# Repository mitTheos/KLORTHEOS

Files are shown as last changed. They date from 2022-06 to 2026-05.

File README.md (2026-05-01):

# Welcome to my take on the great KLOR Split Keyboard Project

My addition to the project includes the addition of a 5 way switch to the thumb cluster for the LP KS55 version with the revision 1.5.

I got inspiration for the usage of a 5way switch from [the Fulcrum project](https://github.com/dschil138/Fulcrum) and found the there described uses for it intriguing. The project however went into a different flavor of split kb then what I was looking for. The KLOR on the other hand matching that very well. My keyboard of choice before the KLOR was a Sofle. Which I was very happy with but still left somethign to be desired. Ultimately I wanted a keyboard that was:
- wireless
- had stronger row stagger than the Sofle
- had 5way switches
- had rotary encoders
- low profile
- used less keys than the Sofle

I think with my modification of the KLOR I should be able to check all of these boxes.

*To note: for the addition of the 5 way switch I removed the switch 22 (obviously) but also the audio buzzer and the trackball modules to make more space. I have no intention of using either one and the additional space that came with removing them made the routing a tad easier which was welcome as this was my first take on PCB modification.*

# Lefuneste's notes
Here you'll find an up do date version of KLOR PCB and firmware files for Rev 1.4 for full height Cherry switches and a Rev 1.4 LP KS33 version for low profile KS33 Gateron switches.

If you intend to build a KLOR keyboard from this repo please take the time to read the different sections below.

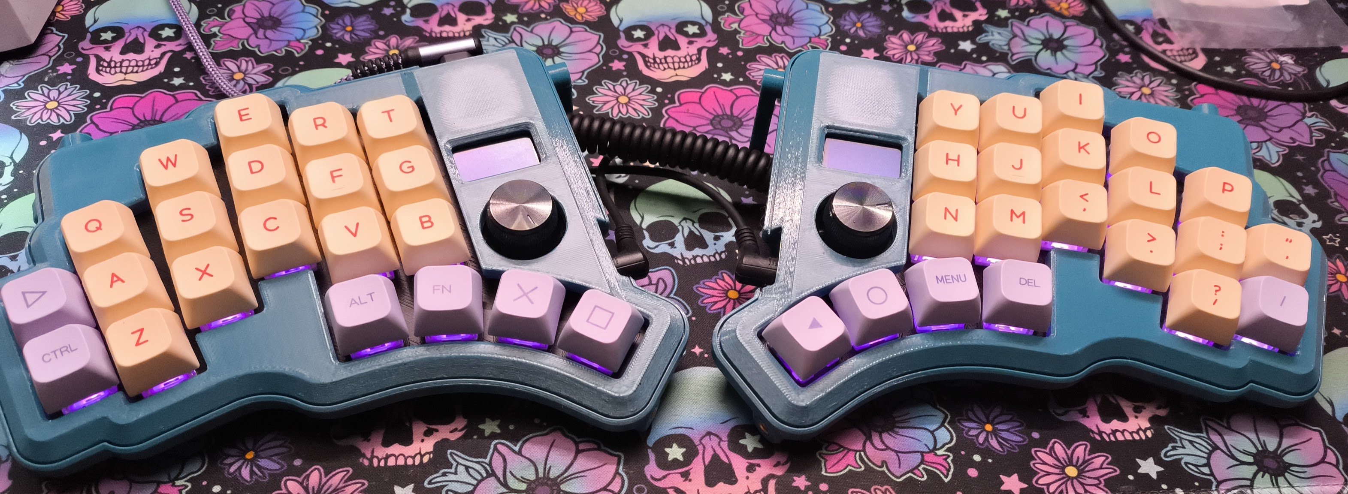
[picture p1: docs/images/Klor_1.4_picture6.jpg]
KLOR

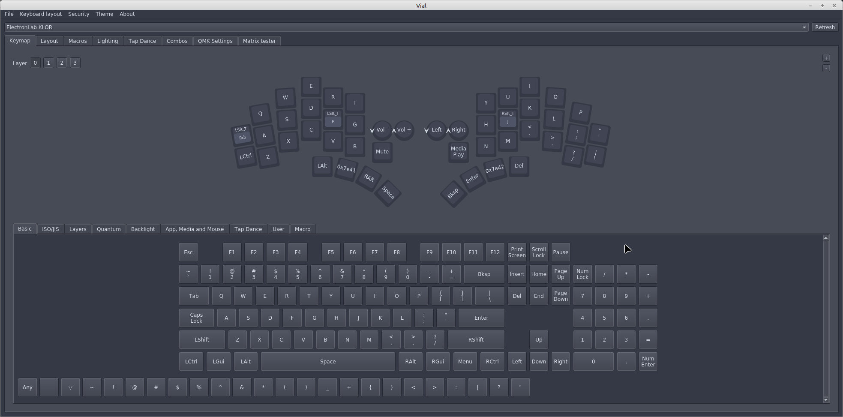
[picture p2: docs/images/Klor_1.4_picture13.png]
KLOR


### [CHANGELOG](https://github.com/Lefuneste83/KLOR/blob/main/CHANGELOG.md)

### [PCB FOR FULL HEIGHT SWITCHES (REV 1.4)](https://github.com/Lefuneste83/KLOR/tree/main/PCB/klor1_4)
-  This is my original initial design, derived from the 1.3 with lots of upgrades. I have built it and it works great. The south facing LED and the better suited LED packages make this the best choice for a first KLOR build. It keeps the overall design of the original in terms of PCB size and modularity. It is designed for MX style full height hotswap sockets. Gateron or Kailh sockets work great and probably other brands as well. This is not compatible with low profile sockets!

### [FABRICATION NOTES (FOR REV 1.4)](https://github.com/Lefuneste83/KLOR/blob/main/FABNOTES.md)
- These are my recommendations for first time builders of the KLOR keyboard. I suggest to have a read as they explain most tricky points that I have encountered while building mine.

### [PCB FOR LOW PROFILE GATERON KS33 SWITCHES (BETA VERSION REV 1.4 LP KS33)](https://github.com/Lefuneste83/KLOR/tree/main/PCB/klor1_4_LP_KS33)
-  This is a beta version derived from the 1.4 using low profile Gateron hotswap sockets for KS33 switches. It is a beta version so it will see lots of updates in the coming days. Don't rush to have it made except if you want to test it. In particular the haptic module will most likely interfere with the sockets and will require some filing of the haptic PCB. So it is not perfect yet.

### [PCB FOR ALTERNATIVE HAPTIC MODULE](https://github.com/Lefuneste83/KLOR/tree/main/PCB/Alternate%20DIY%20Haptic%20Module)
-  This is an alternative version of the haptic module for those who don't want to spend a fortune on the original one or can't source it. It is for advanced users as you will need some experience in SMD soldering and a hot air or hot plate to solder the linear actuator, and some form of magnification for the driver chip. It works great and is a bit shorter for easier integration. It mounts perfectly on all PCB versions except most likely on the low profile PCB because of the interference with the hotswap socket.

### [PCB FOR FULL HEIGHT SWITCHES CORRECTED STOCK VERSION (REV 1.3)](https://github.com/Lefuneste83/KLOR/tree/main/PCB/klor1_3)
-  This is as close as it gets to the original design but with some rerouting to allow to pass JLCPCB preproduction validation process. It uses the older style of LED (WS2812 3535) which are very tricky to solder properly, as they are not intended to be mounted this way. I strongly suggest moving to the 1.4 version for a much better build experience and a much more reliable build.

### [FIRMWARE](https://github.com/Lefuneste83/KLOR/blob/main/FIRMWARE.md)
-  VIAL support is now working on RP2040 with VIAL-QMK
-  These are updated QMK and ZMK config files and compiled images. They should have most devices enabled by default and should compile on latest toolchains of ZMK and QMK. A [Github Actions repositiry for ZMK](https://github.com/Lefuneste83/zmk-config-klor) is also available in my other repositories. Keep in mind that I only use ZMK on NRF52840 and QMK on RP2040. I would advise you to do the same as Atmega chips will not support all functionalities of the KLOR keyboard. As a reminder ZMK on NRF52840 will not support audio or haptic yet, but will support OLED to a certain degree and wireless communications with BLE protocol. QMK on RP2040 will support everything except wireless communications.

# CONTEXT
I have just completed my build of the 1.3 and found it a bit frustrating to assemble, despite my 13 year experience with this kind of project. Don't get me wrong the KLOR project is absolutely marvelous, but the PCB design starts to show its age IMHO, in the details of the layout in particular. Technology wise it is one, if not the best project out there hands down.

So here you will find a completely refactored PCB design of the KLOR project for 2024 including :

- Much better suited and easier to solder ARGB modules. I have used SK6812 Mini-E (aka 6028 size LED) version as it is the typical choice for this kind of keyboard application. I have thus kept the original paradigm of through hole design, with a symetrical front/back layout, but while using a LED module which is designed for this application, contrary to the original model WS2812 3535 which required a direct "hanged" soldering, with very likely damages to the plastic package as well as missalignment issues, as this part is designed for direct surface mount. I personnaly think that it would be even better to use the new WS2812 2020 package which is very neat, but as this is a strictly SMD part, there is no need for discrete cutouts anymore, so the design would look a bit different. Also you need to master SMD soldering. Let me know if you are interested in this type of LED package, I could make a forked design without too much fuss.

- As Hipyo Tech can confirm, we are in 2024 so no North facing LED are allowed anymore. I have moved to South facing LED.

- I have tried to keep the overall design paradigm so all the good stuff is still there!!

- I have very extensively refactored the PCB layout (3 days of intense work) to clean up the various little issues that were sprinkled around the original design including :

  Rerouting of 90% of the PCB. Healthier and more rational overall routing, at least that's my belief...
  
  Change to the footprint of the solder jumpers to triangular shapes much easier to bridge
  
  Correction of missing ground connections on the various switches bodies
  
  Dual ground planes thorough validation (this was painful)
  
  Very slight changes to the board cutout on the right side, to deal with reversed switch placement. Also very slight reduction of the cutout under the top of the MCU to catter some track celearance that would pop up in DRC. This should have no impact as this cutout serves no real purpose as far as I know. Cases and switchboards should mount the same, except for the ones using the puck cutout (see below).
  
  Very slight movement of the puck mounting holes downward (98.57 mm instead of 96.4 mm) by a couple milimeters to catter for reversed switches pad postions. I could not do otherwise without revisiting the switch layouts. I could not solve this by rotating the 3 mounting holes without interfering with other nets. It should not affect the mounting ability of the puck itself, but it WILL interfere with existing back cases using the puck cutout. So we will need specific cutouts for the case. As I don't have access to the original step model the best option would be to use some alternate case design provided with source files in order to lower the cutout by the same amount (2.17 mm).
  
  I managed a 0 error JLCPCB DRC, with only very few voluntary exceptions (down from 1000+). It took me several hours to clean up the various little issues that were sprinkled all around the orignial design. And I can confirm that Kicad on Linux is not a pleasure to use...
  
  Change of Logo with mine !

  This repo will be updated as I have new ideas for integrations of various tech or correction for errors.

  I have also included files for a working 1.3 design which passes the JLCPCB fabrication and is working as a real world product (REV 1.3)
  
***

<picture>
  <source media="(prefers-color-scheme: dark)" srcset="/docs/images/klor-font-logo-dark.svg">
  <source media="(prefers-color-scheme: light)" srcset="/docs/images/klor-font-logo-bright.svg">
  KLOR logo font
</picture>

# KLOR SPLIT KEYBOARD

KLOR is a 36-42 key column-staggered split keyboard. It supports a per-key RGB matrix, encoders, OLED displays, haptic feedback, speakers, a Pixart Paw3204 trackball, the [SplitKB tenting puck](https://splitkb.com/products/tenting-puck), and four different layouts, through break-off parts.

***

## RENDERING OF THIS FORK (Rev 1.4)

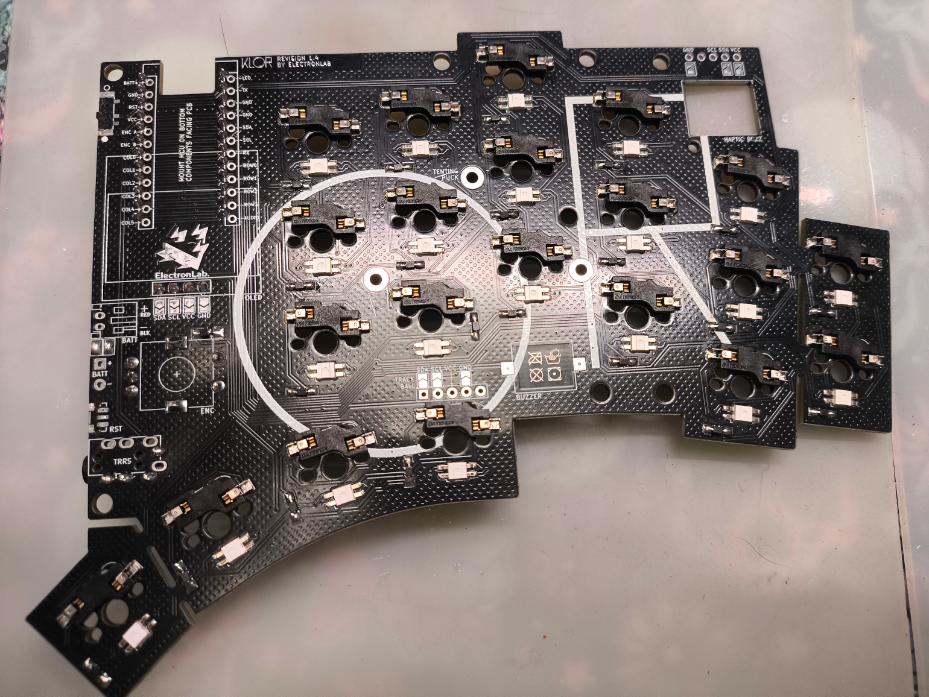
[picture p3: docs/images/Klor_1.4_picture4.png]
KLOR layouts

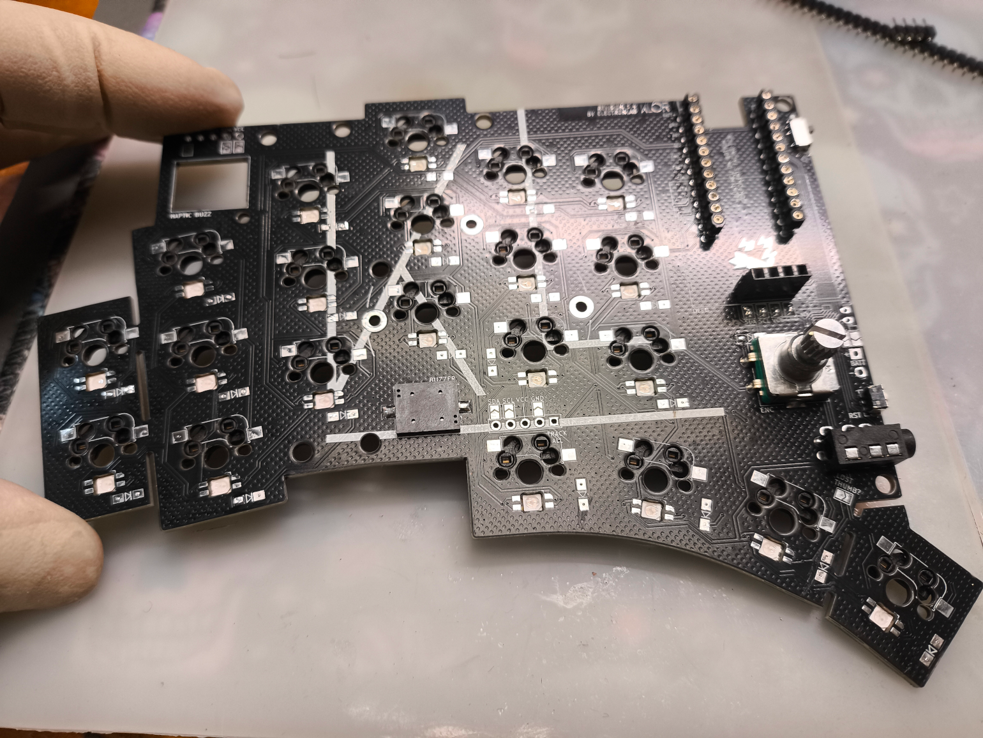
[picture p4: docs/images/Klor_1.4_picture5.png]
KLOR layouts

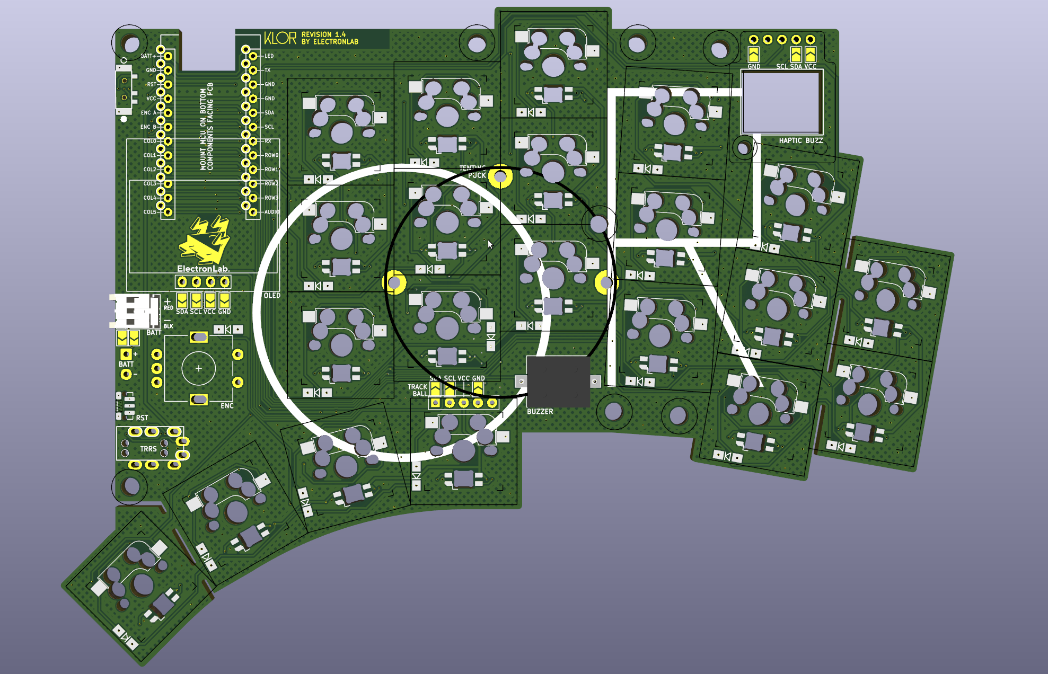
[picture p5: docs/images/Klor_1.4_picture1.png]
KLOR layouts

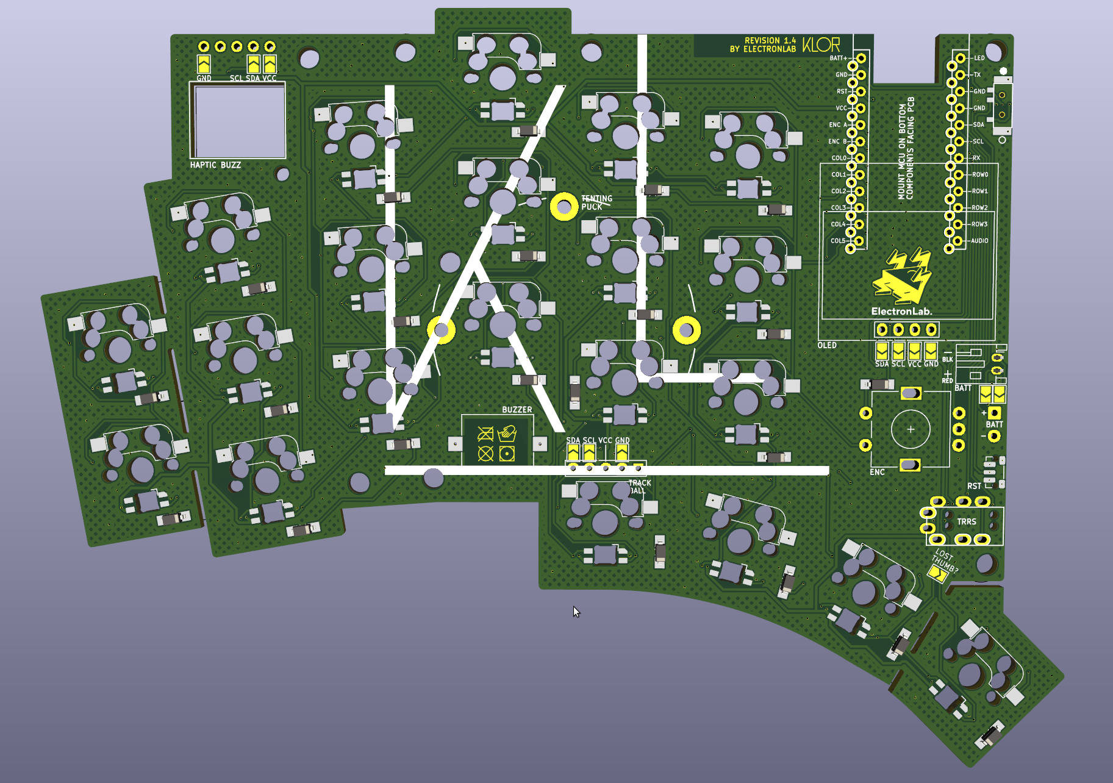
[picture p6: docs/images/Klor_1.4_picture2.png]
KLOR layouts

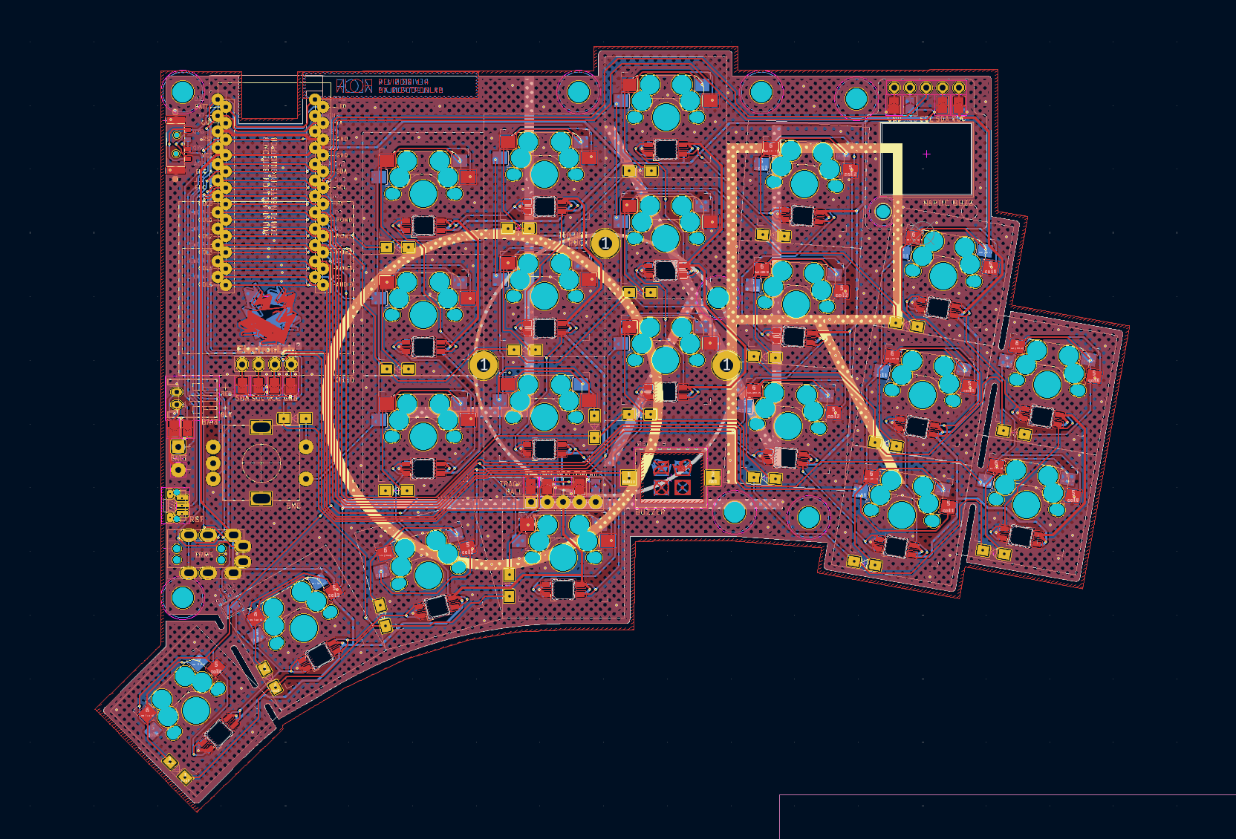
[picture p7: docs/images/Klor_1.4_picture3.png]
KLOR layouts


***

## LAYOUTS

KLOR layouts

***

## PCB 

[Here](/PCB/) you can find the KiCad files and Gerbers for the KLOR 1.3 (tested working with JLCPCB) and 1.4 (this version). 

***

## CASE

[Here](/case/) are the case files for the KLOR. There is an acrylic case and a 3D printed case (which uses acrylic too) for every layout.

***

## SWITCHPLATE

In every case directory you'll find the matching switchplates as **.dxf**, **.svg**, **.stl**, and a **.zip**-file, containing gerber files for a FR4 plate.

***

## KNOB

You can use pretty much any knob, which works with the EC11 encoder, but [here](/knob/) you can find one, I designed for the KLOR.

***

## BUILD GUIDE

Here you can find the build guides for the KLOR.\
[KLOR build guide 3DP case](/docs/buildguide_3DP.md) (QMK)\
[KLOR build guide stacked acrylic case](/docs/buildguide_acrylic.md) (QMK)\
[KLOR BLE build guide 3DP case](/docs/buildguide_3DP_ble.md) (ZMK)\
[KLOR BLE build guide stacked acrylic case](/docs/buildguide_acrylic_ble.md) (ZMK)

***

## CHOC/KS27 VERSION

[Sadek Baroudi](https://github.com/sadekbaroudi) did an amazing job in creating a version of the KLOR which supports KS-27 and Choc V1 switches. Including a special case for it.\
[KLOR Sadek KS-27 and Choc V1 mod](https://github.com/sadekbaroudi/KLOR)

***

## CREDITS

The KLORs hardware is based on the [Sofle](https://github.com/josefadamcik/SofleKeyboard) by [Josef Adamcik](https://github.com/josefadamcik).\
Other inspirations are 
- [Kyria](https://splitkb.com/products/kyria-pcb-kit) by [Thomas Baart](https://github.com/splitkb)
- [Yacc46](https://github.com/1m38/keyboards/tree/main/yacc46) by [1m38](https://github.com/1m38)
- [Elephant42](https://github.com/illness072/elephant42) by [illness072](https://github.com/illness072)
- [Torn](https://github.com/rtitmuss/torn) by [Richard Titmuss](https://github.com/rtitmuss)
- [Claw44](https://github.com/yfuku/claw44) by [yfuku](https://github.com/yfuku)

I used the Pimoroni Haptic Buzz Footprint from the [Buzzard](https://github.com/crehmann/Buzzard) by [Christoph Rehmann](https://github.com/crehmann).

***

People who helped me create this board and fix stuff
- [KarlK90](https://github.com/KarlK90)
- [MangoIV](https://github.com/MangoIV)
- [OxCB](https://github.com/0xCB-dev)
- [MicroFortnight](https://github.com/microfortnight)
- [dreipunkteinsvier](https://github.com/dreipunkteinsvier)

If you build a KLOR I would be pretty happy to see some pictures. And if you want to leave me a tip you can do this [here](https://ko-fi.com/geigeigeist) (but please don't feel pressured)

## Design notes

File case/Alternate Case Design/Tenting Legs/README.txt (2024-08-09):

Tenting legs by chewiedies on Thingiverse: https://www.thingiverse.com/thing:5382293

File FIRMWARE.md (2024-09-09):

# FIRMWARE
My version of ZMK firmware  with Github Actions pipeline is [located here](https://github.com/Lefuneste83/zmk-config-klor):

It has both encoders working, precise pulse per rotation adjustments and RGB enabled by default.

Config files for both QMK and ZMK can be [found here](https://github.com/Lefuneste83/KLOR/tree/main/FIRMWARE):

For extra convienence if you intend to modify your firmware for a smaller layout, I have created a link to :

 -  A [full POLYDACTYL layout](http://www.keyboard-layout-editor.com/#/gists/8ff2b448f2ef6c56c2b932e83ebf040f)
 -  A [KONRAD layout](http://www.keyboard-layout-editor.com/#/gists/49ff09e68b46feb39760467424a4601a)
 -  A [YUBITSUME layout](http://www.keyboard-layout-editor.com/#/gists/dc3fdb427b3102ccbf85252e2e278918)
 -  A [SAEGEWERK layout](http://www.keyboard-layout-editor.com/#/gists/b3775d73a84de0d544ea3bf84bafb047)

****

-  Added support for VIAL firmware for RP2040 boards. You can now compile :
   
      the "default" layout using [QMK toolchain](https://github.com/qmk/qmk_firmware) and the command :

            qmk compile -kb electronlab/klor -km default -c
   
      or "vial" layout using [vial-qmk toolchain](https://github.com/vial-kb/vial-qmk) and the command :

            make clean && make electronlab/klor:vial
    
-   Also be aware that I have now enabled firmware based handedness definition ([#define EE_HANDS setting](https://docs.qmk.fm/features/split_keyboard)) so you should flash the firmware using the following commands for left and right keyboard sides :
-   
   For QMK environment
    
             qmk flash -kb electronlab/klor -km default -c -bl uf2-split-left
             qmk flash -kb electronlab/klor -km default -c -bl uf2-split-right
    
  For VIAL-QMK environment
     
             qmk flash -kb electronlab/klor -km vial -c -bl uf2-split-left
             qmk flash -kb electronlab/klor -km vial -c -bl uf2-split-right

-  Make sure you switch your serial communication to HALF DUPLEX as software pin swap used for full duplex does not seem to work well with firmware based handedness detection. If you alyays want to plug one side of the keyboard then you can set the master side in config.h and switch to full duplex with software pin swap. This will require a little testing but it will work eventually

-  While playing with QMK I have noticed that the original 1.3 design carried a wiring flaw on the minijack footprint and PCB traces. The RX/TX are symetrical between the two sides which makes it impossible to define the transmission protocol in QMK as serial full duplex with RP2040 ProMicro boards if you don't specify a pin swap command. By default the stock firmware uses bitbang driver on a single pin which is not optimal and made the use of a TRRS link unnecessary as 3 pins cable would suffice. If you use these boards you should set the following in the config.h for QMK if using RP2040 ProMicro boards.
      
                  //Full Duplex communication
                  #define SERIAL_USART_TX_PIN GP4     // USART TX pin
                  #define SERIAL_USART_RX_PIN GP1     // USART RX pin
                  #define SERIAL_USART_FULL_DUPLEX
                  #define SERIAL_USART_PIN_SWAP

-  In case your MCU can only use a single pin for communications, it is recommended to use half duplex serial instead of bitbang.
      
                  //Half Duplex communication
                  //#define SERIAL_USART_TX_PIN GP1     // USART TX pin
       
-  More about this matter [here](https://docs.qmk.fm/drivers/serial)

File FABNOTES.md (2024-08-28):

# FABRICATION NOTES FOR MAIN 1.4 VERSION
-  Compared with 1.3 design you only need different LED modules (SK6812 Mini-E instead of WS2812 3535). Beware that this PCB uses the most common SK6812 Mini-E package, but there are many variants around including reversed wired one or similar packages with non addressable RGB. In doubt check the wiring in Kicad. If ordering on Aliexpress you should generaly be safe when looking for this part but always double check the pinout.

-  Beware that Gateron hot swappable sockets must be oriented properly with their rounded edge against the central hole. If mounted upside down you won't be able to insert the switch. Kailh sockets don't have the same symetry in their shape so no risk to mount them upside down.

-  Be careful when selecting your hot swappable sockets as all brands have normal and low profile options with different pin placements. You can only use normal sockets on the main 1.4 version. There is also a low profile version for Gateron KS33/V2 low profile switches that I haven't assembled yet. Use with caution!

-  I recommend you stick with recommended diodes 1N4148W in SOD123 package. Too small diodes can be a pain to orientate properly without proper magnification

-  Choose your MCU wisely: for wireless connectivity, Nice Nano V2 is fine and kind of the only option at this moment. But you'll loose some functionalities such as speaker, haptic feedback and less display used for logos. On the bright side I can confirm that both encoders do work flawlessly with recent versions of ZMK. When you wish to make the extra steps, ZMK firmware is a bit tricky to setup properly, but with some time you may be able to implement what you want. Keep in mind that the current official Firmware is based on an older ZMK codebase and some significant changes have happened recently, in terms of syntax, making it almost mandatory to do some changes in the original config and devicetree files (for instance in order to have precise pulses per rotation for each encoder or to enable RGB)

-  For wired builds I now only recommend RP2040 Pro Micro boards as it seems very compatible with QMK and much more powerful compared with ATMega32U4 MCU wich is outdated now. As I have recently ventured deeper into QMK, it appears that when using their latest toolchain and build definitions, the Atmega cannot hold all functionalities in its memory. So you'll definitely need to go the RP2040 route for a full set of specs. QMK is very good IMHO apart from not having proper wireless options which is a real bummer... It is also in the middle of a heavy transformation in its file structure (migration to a single keyboard.json for all metadata) and the provided stock firmware which is several year old will hardly compile at all against the latest QMK code base. So at the moment the easiest route is to flash the already compiled firmware or try ZMK.

-  The stock Pimoroni haptic feedback modules are extremly expensive at around 15 Euros each before shipping and are only offered by one single manufacturer. I have designed a DIY version of this module that should fit nicely. This module requires some SMD skills and equipment to be assembled. Parts values can be found on TI documentation for the driver chip itself. I will be using 2.2k pullup resistors and 1uF capacitors. Diode is optional and will serve as a reverse polarity protection. Same model as the rest of the keyboard could be used. Voltage drop should not be an issue as the driver chip will work with VCC ranging from 2 to 5.5V.

-  There are currently no neat and proper options for socketed MCU mount in order to keep a very low profile while being socketed. So far the best option is to use machined round pins female headers with some sort of wire or salvaged through hole part leg to act as male pins. The expected pin diameter matching the round female headers is around 0.5 mm. Complementary male round pins headers end up beeing a bit too high IMO. I am considering getting some 0.5 mm gold plated wire to act as male pins. Dedicated discrete machined pins in the correct size are outrageously expensive.

-  Power switch (The sliding one at the top) is only useful if you intend to use a battery as your main power source typically for a wireless build. I recommend to NOT populate it if your primary goal is to build a wired version of this keyboard. It will save you a little money. It serves no purpose at all for wired versions and can interfere with the enclosure and switch plates. It is also very delicate and not very ergonomic. The reset switch on the contrary will serve you every time you intend to flash your MCU, even when bootmagic is enabled it is always useful to have it.

-  You can choose to mount the reset switch, power switch and TRRS jack either side of the PCB. I think it is better to put them all on the upper side along with the rotary encoders, but the circuit is symetrical so they will work whatever side you choose apart from the minijack which has a specific requirement (see below). Most cases account for an upper side mount so just check with your case design. Stencils will provide openings to put paste on either sides so obviously use them (or not) as required.

-  Due to the way both sides communicate you should make sure you solder both minijack on the same side top or bottom in order to have a properly crossed RX TX pins between the two boards. This allows the use of serial full duplex protocol when using RP2040 boards with QMK.

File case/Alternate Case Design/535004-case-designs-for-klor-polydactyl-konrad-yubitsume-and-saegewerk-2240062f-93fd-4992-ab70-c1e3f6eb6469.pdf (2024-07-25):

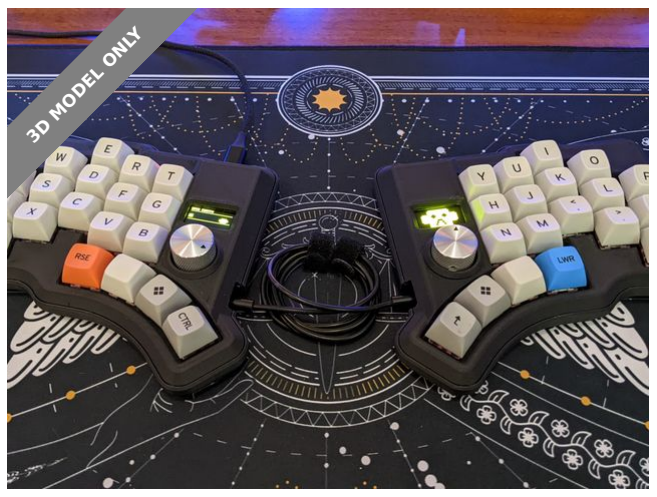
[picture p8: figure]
3D MODEL ONLY

## Summary

This is a case design for all four variants of the KLOR by GEIST

Gadgets (https://printables.com/model?categoryId=21) > Other Gadgets (https://printables.com/model?categoryId=43)

These are gasket mount case designs with optional tenting for KLOR. All four variants are supported. The top and bottom pieces fasten with 6mm x 3mm neodymium magnets. The optional tenting fastens via M3 heatset inserts. The lid pieces support encoder knobs up to 24mm. There are encoder inserts to accommodate knobs of a smaller diameter (20mm and 16mm).

IMPORTANT: The case design requires the MCU be mounted on TOP of the PCB with its components facing up. MCU sockets are recommended. The OLED screens were mounted with IC SIP sockets to allow it to be mounted low enough to fit in the case. Some low profile MCU sockets would also suffice.

M3 Inserts: https://www.amazon.com/gp/product/B09ZNXRD2H/ref=ppx_yo_dt_b_search_asin_title?ie=UTF8&th=1 (https://www.amazon.com/gp/product/B09ZNXRD2H/ref=ppx_yo_dt_b_search_asin_title?ie=UTF8&th=1)

Magnets: https://www.amazon.com/DIYMAG-6x3mm-Refrigerator-Premium-Brushed/dp/B07KZQGWNN (https://www.amazon.com/DIYMAG-6x3mm-Refrigerator-Premium-Brushed/dp/B07KZQGWNN)

chewiedies (https://printables.com/@chewiedies_360738)

## Case designs for

KLOR (Polydactyl,
Konrad, Yubitsume,

## and Saegewerk,)

VIEW IN BROWSER (https://printables.com/model/535004-case-designs-for-klor-polydactyl-konrad-yubitsume)

updated 2. 7. 2024 | published 2. 7. 2024

## Model files

3mm Foam: https://www.amazon.com/Neoprene-Adhesive-Padding-Multi-Function-Soundproof/dp/B08RB2FWVR/?th=1 (https://www.amazon.com/Neoprene-Adhesive-Padding-Multi-Function-Soundproof/dp/B08RB2FWVR/?th=1)

1mm Foam: https://www.amazon.com/gp/product/B07L6KV4QG/ref=ppx_yo_dt_b_search_asin_title?ie=UTF8&psc=1 (https://www.amazon.com/gp/product/B07L6KV4QG/ref=ppx_yo_dt_b_search_asin_title?ie=UTF8&psc=1)

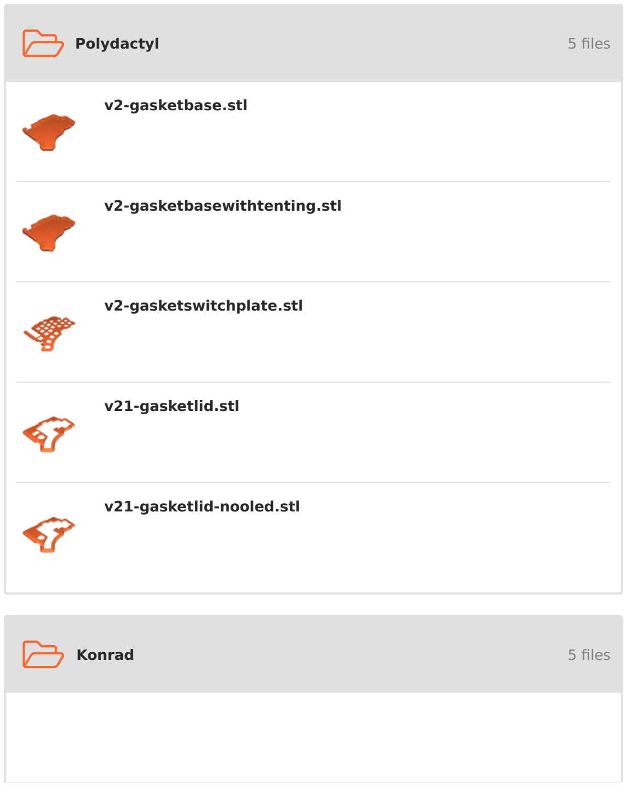
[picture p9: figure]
Polydactyl; 5 files; Konrad; v2-gasketbase.stl; v2-gasketbasewithtenting.stl; v2-gasketswitchplate.stl; v21-gasketlid.stl; v21-gasketlid-nooled.stl

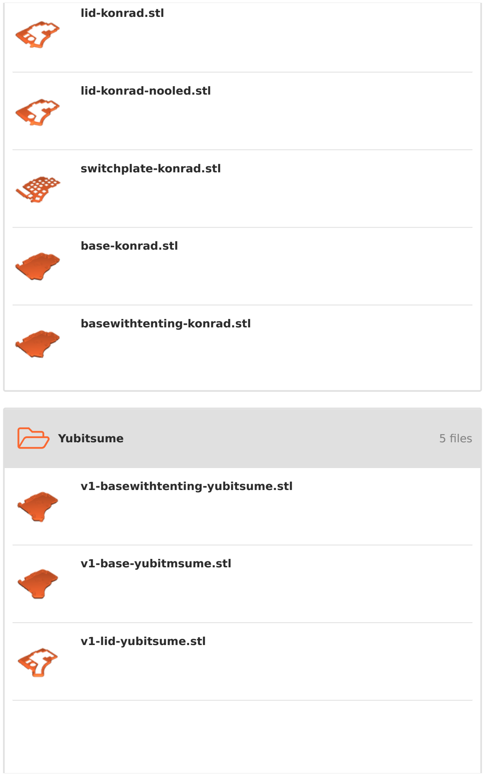
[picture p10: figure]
Yubitsume; 5 files; lid-konrad.stl; lid-konrad-nooled.stl; switchplate-konrad.stl; base-konrad.stl; basewithtenting-konrad.stl; v1-basewithtenting-yubitsume.stl; v1-base-yubitmsume.stl; v1-lid-yubitsume.stl

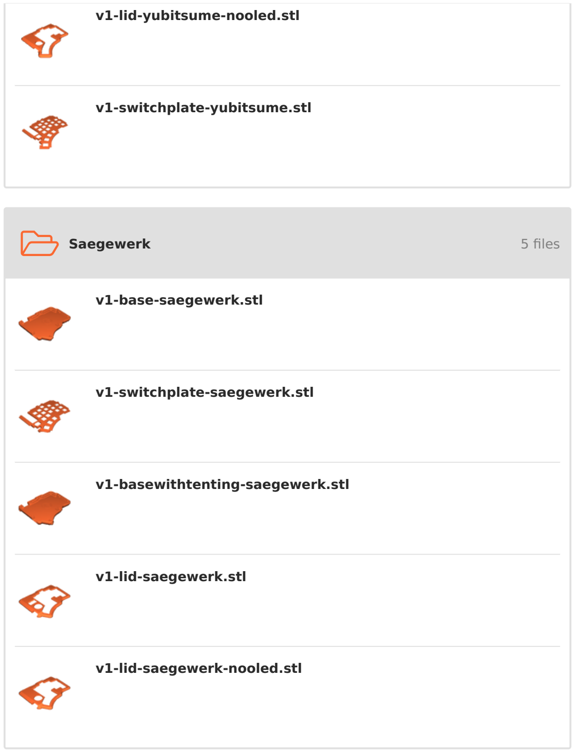
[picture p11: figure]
Saegewerk; 5 files; v1-lid-yubitsume-nooled.stl; v1-switchplate-yubitsume.stl; v1-base-saegewerk.stl; v1-switchplate-saegewerk.stl; v1-basewithtenting-saegewerk.stl; v1-lid-saegewerk.stl; v1-lid-saegewerk-nooled.stl

encoderinsert-flat-16mm.stl

## License

This work is licensed under a
Creative Commons (4.0 International License)

Attribution—Noncommercial—Share Alike (http://creativecommons.org/licenses/by-nc-sa/4.0/)

✖ | Sharing without ATTRIBUTION
✔ | Remix Culture allowed
✖ | Commercial Use
✖ | Free Cultural Works
✖ | Meets Open Definition

encoderinsert-flat.stl

encoderinsert-16mm.stl

encoderinsert.stl

klor-case-designs-v52.step

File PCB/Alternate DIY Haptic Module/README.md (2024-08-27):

## RENDERING OF THE ALTERNATIVE HAPTIC MODULE
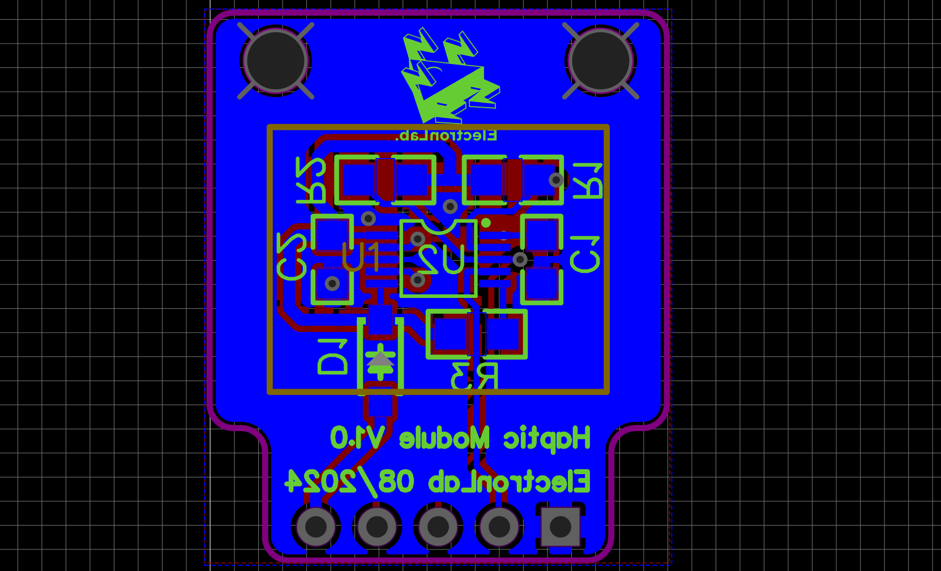
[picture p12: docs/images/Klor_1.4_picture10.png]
KLOR layouts

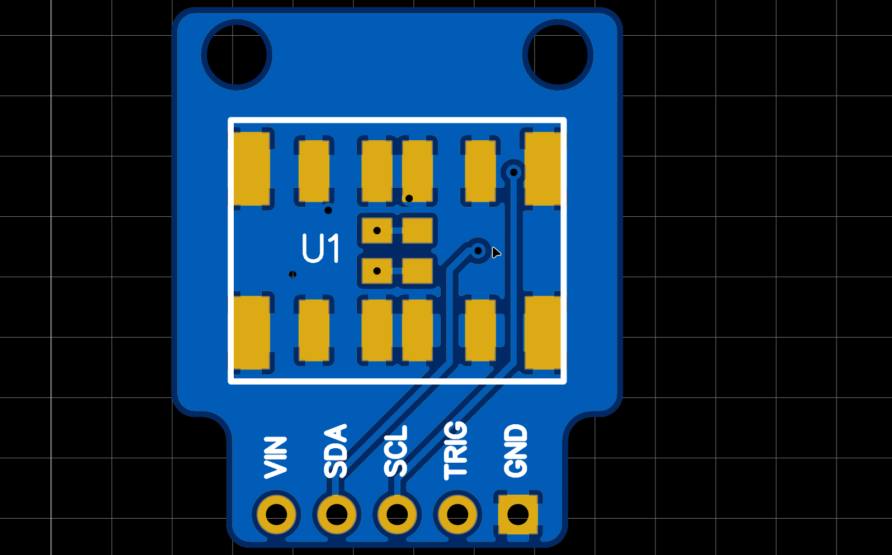
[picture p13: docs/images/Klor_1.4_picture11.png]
KLOR layouts

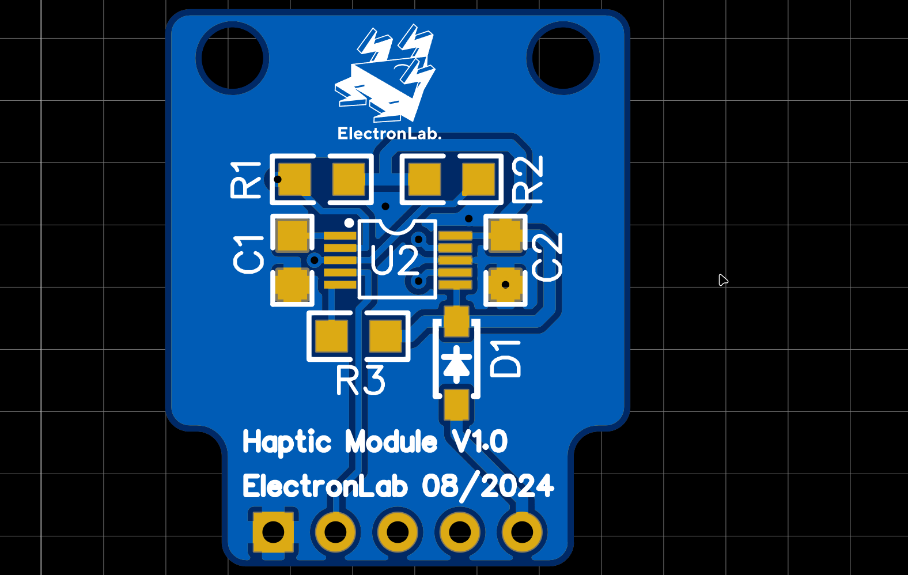
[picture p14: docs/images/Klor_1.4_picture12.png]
KLOR layouts


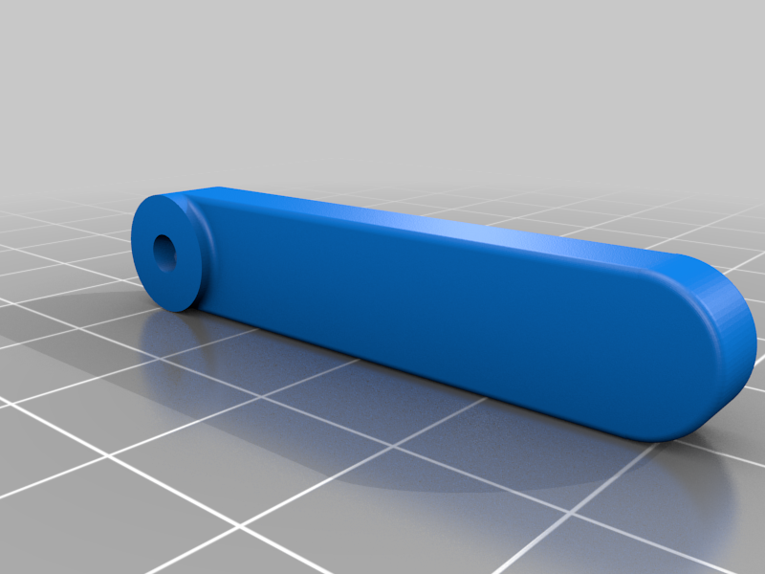
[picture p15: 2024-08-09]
case/Alternate Case Design/Tenting Legs/images/tentingLeg42mm.png

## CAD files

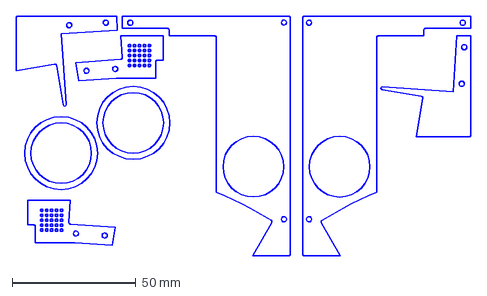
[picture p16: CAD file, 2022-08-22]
case/3DP/konrad/acrylic/KLOR_konrad_3DPcase_acrylic.dxf
183.7 x 96.8 mm

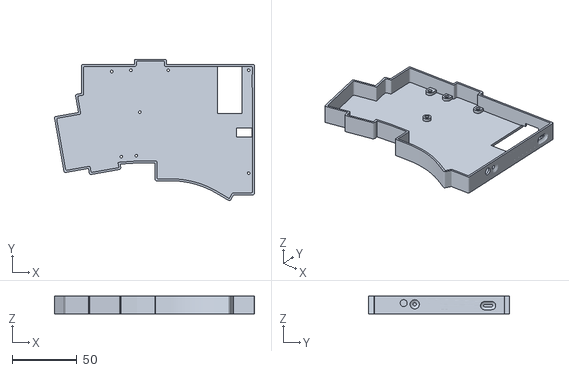
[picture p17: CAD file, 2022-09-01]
case/3DP/konrad/bluetooth/KLOR_konrad_case_ble_L.stl
154.3 x 109.2 x 13.6

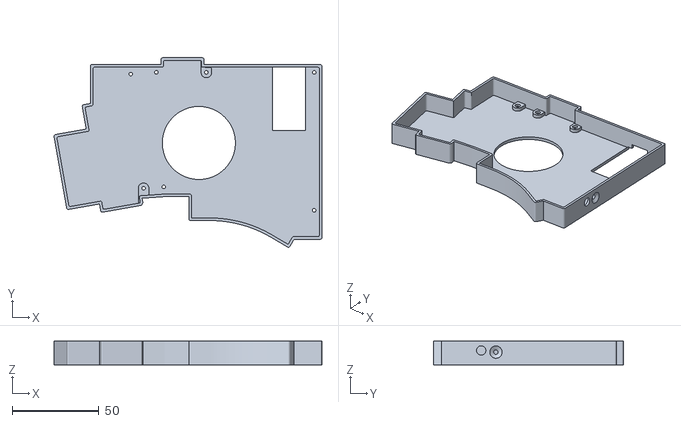
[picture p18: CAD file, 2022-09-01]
case/3DP/konrad/regular/KLOR_konrad_case_puck_L.stl
154.3 x 109.2 x 13.6

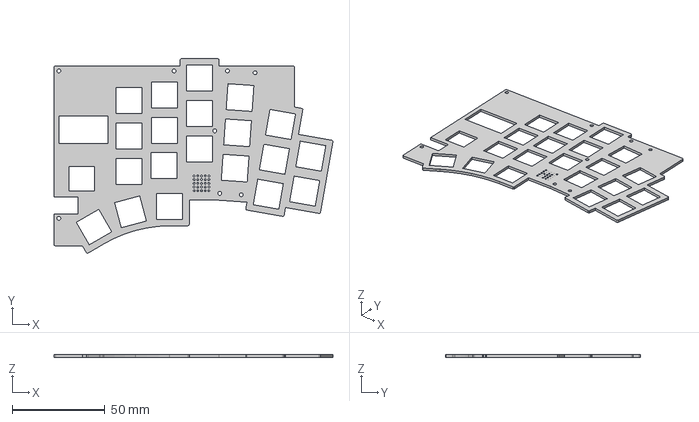
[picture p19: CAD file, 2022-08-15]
case/3DP/konrad/switchplate/KLOR_konrad_3DP_switchplate.step
150.3 x 104.8 x 1.50 mm

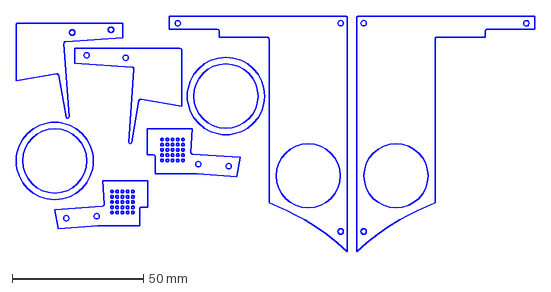
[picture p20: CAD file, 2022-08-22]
case/3DP/polydactyl/acrylic/KLOR_polydactyl_3DPcase_acrylic.dxf
197.8 x 89.7 mm

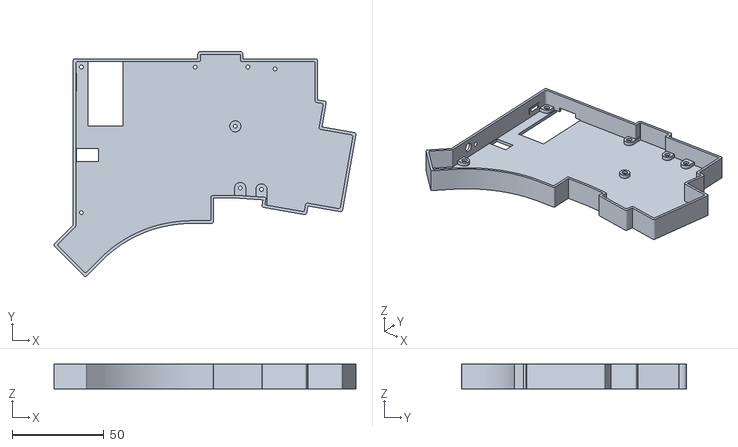
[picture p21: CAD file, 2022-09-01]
case/3DP/polydactyl/bluetooth/KLOR_polydactyl_case_ble_R.stl
164.7 x 122.7 x 13.6

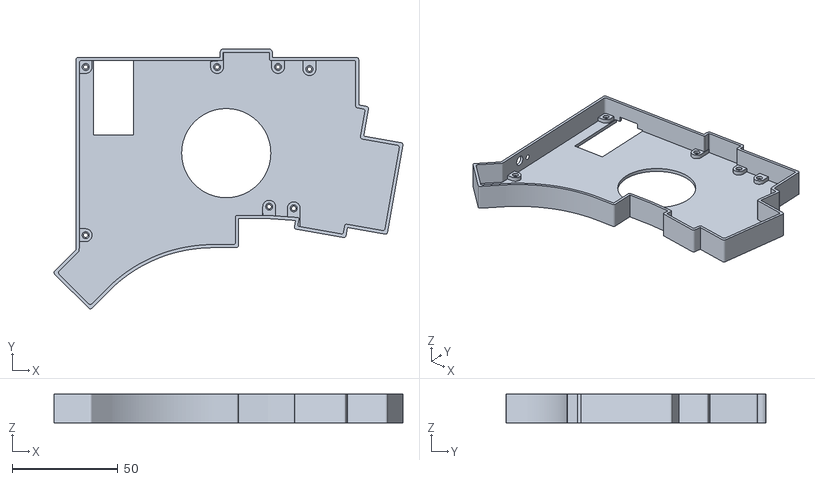
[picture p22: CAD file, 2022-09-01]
case/3DP/polydactyl/regular/KLOR_polydactyl_case_puck_R.stl
164.7 x 122.7 x 13.6

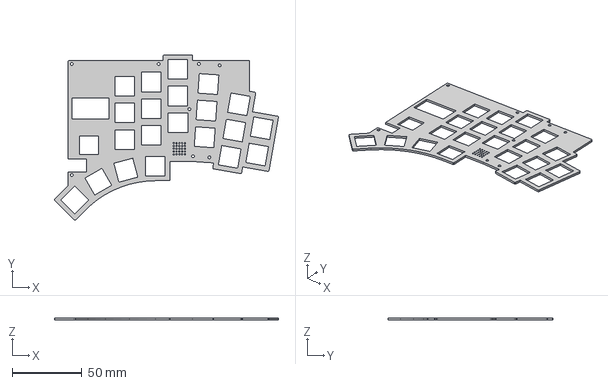
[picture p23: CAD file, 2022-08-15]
case/3DP/polydactyl/switchplate/KLOR_polydactyl_3DP_switchplate.step
160.0 x 118.2 x 1.50 mm

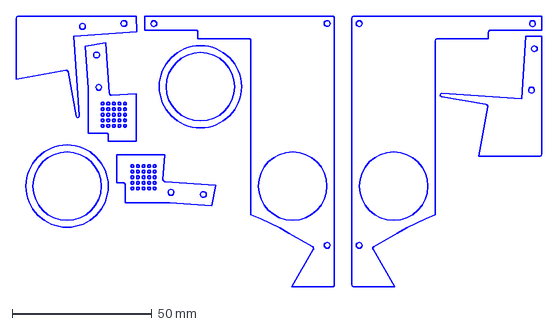
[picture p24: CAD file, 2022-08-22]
case/3DP/saegewerk/acrylic/KLOR_saegewerk_3DPcase_acrylic.dxf
188.1 x 96.8 mm

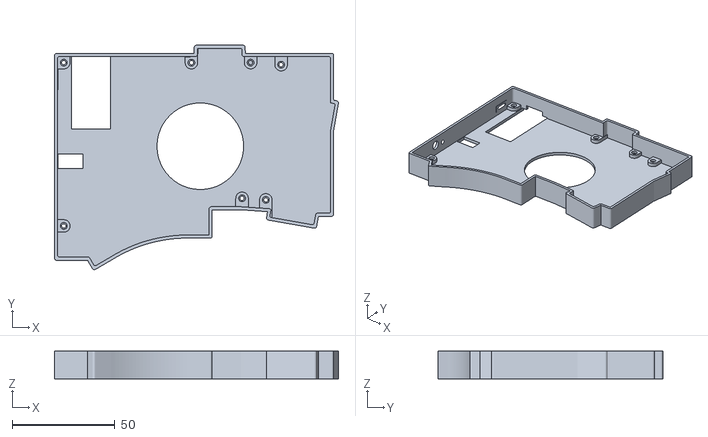
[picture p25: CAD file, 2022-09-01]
case/3DP/saegewerk/bluetooth/KLOR_saegewerk_case_puck_ble_R.stl
138.1 x 109.2 x 13.6

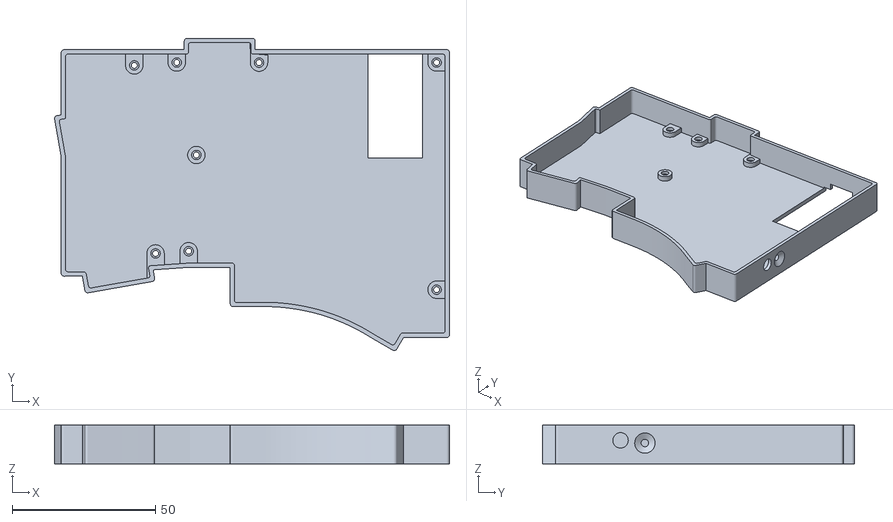
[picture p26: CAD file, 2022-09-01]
case/3DP/saegewerk/regular/KLOR_saegewerk_case_L.stl
138.1 x 109.2 x 13.6

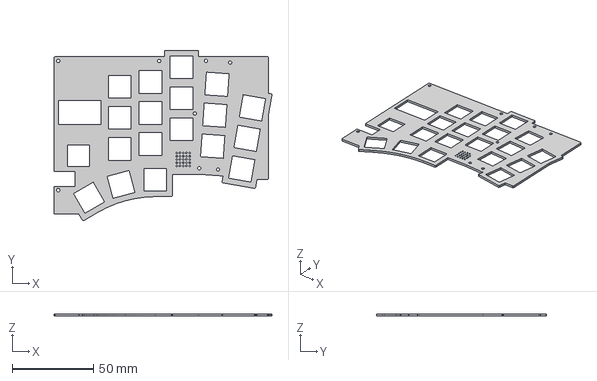
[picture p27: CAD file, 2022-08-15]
case/3DP/saegewerk/switchplate/KLOR_saegewerk_3DP_switchplate.step
134.0 x 104.8 x 1.50 mm

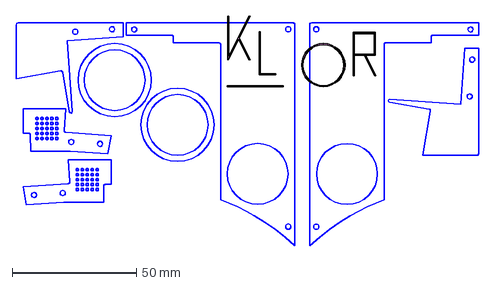
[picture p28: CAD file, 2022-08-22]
case/3DP/yubitsume/acrylic/KLOR_yubitsume_3DPcase_acrylic_logotype.dxf
186.0 x 92.4 mm

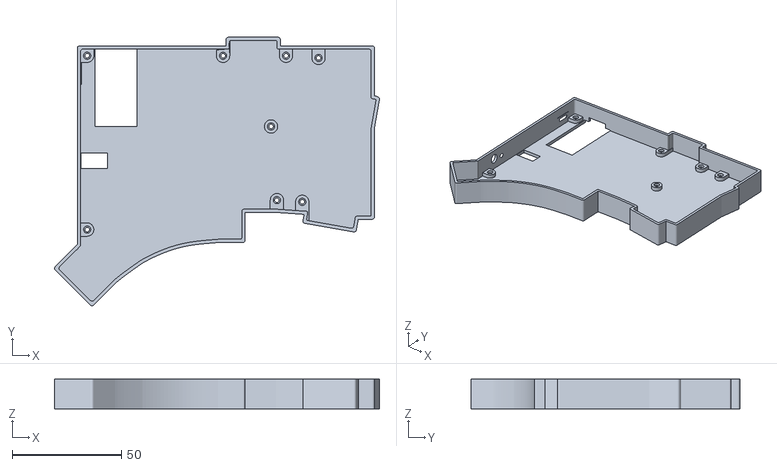
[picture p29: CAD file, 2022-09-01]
case/3DP/yubitsume/bluetooth/KLOR_yubitsume_case_ble_R.stl
148.4 x 122.7 x 13.6

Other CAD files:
case/3DP/yubitsume/regular/KLOR_yubitsume_case_R.stl
case/3DP/yubitsume/switchplate/KLOR_yubitsume_3DP_switchplate.step
case/acrylic/konrad/switchplate/KLOR_konrad_acrylic_case_switchplate.step
case/acrylic/polydactyl/switchplate/KLOR_polydactyl_acrylic_case_switchplate.step
case/3DP/konrad/acrylic/KLOR_konrad_3DPcase_acrylic_logotype.dxf
case/3DP/konrad/bluetooth/KLOR_konrad_case_ble_R.stl
case/3DP/konrad/bluetooth/KLOR_konrad_case_ble_puck_L.stl
case/3DP/konrad/bluetooth/KLOR_konrad_case_ble_puck_R.stl
case/3DP/konrad/regular/KLOR_konrad_case_L.stl
case/3DP/konrad/regular/KLOR_konrad_case_R.stl
case/3DP/konrad/regular/KLOR_konrad_case_puck_R.stl
case/3DP/konrad/switchplate/KLOR_konrad_3DP_switchplate.dxf
case/3DP/konrad/switchplate/KLOR_konrad_3DP_switchplate.stl
case/3DP/polydactyl/acrylic/KLOR_polydactyl_3DPcase_acrylic_logotype.dxf
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

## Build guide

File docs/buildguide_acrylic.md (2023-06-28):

# KLOR BUILD GUIDE (STACKED ACRYLIC CASE) [WIP]

## PART LIST

### REQUIRED PARTS

| Part name | Count | Remarks | 
| :--- | :---: | :--- |
| KLOR PCB | 02 | You can find the files for it [here](/PCB/) |
| ProMicro | 02 | Alternatively, you can use another controller with a similar pinout like the Elite-C, Puchi-C, KB2040 dda. |
| MX Key switch | 42 | 40 switches for Konrad / 38 switches for Yubitsume / 36 switches for Saegewerk |
| switch socket | 42 | 40 sockets for Konrad / 38 sockets for Yubitsume / 36 sockets for Saegewerk |
| diodes 1N4148W| 44 | These are surface mount diodes in SOD123 package. 42 for Konrad / 40 for Yubitsume / 38 for Saegewerk |
| 1u MX keycaps | 42 | 40 keycaps for Konrad / 38 keycaps for Yubitsume / 36 keycaps for Saegewerk |
| OLED module | 02 | SSD1306 128x64 pixel OLED Displays |
| reset button  | 02 | Alps SKRTLAE010 |
| TRRS jack | 02 | MJ-4PP-9 or PJ320A |
| TRRS cable | 01 | Alternatively, you can use a TRS cable for [half-duplex](https://github.com/qmk/qmk_firmware/blob/master/docs/serial_driver.md#usart-half-duplex)|
| EC11 encoder  | 02 | You can use any EC11 encoder, but it will look better if you use a short one, like the EC11N1524402 |
| encoder knob  | 02 | The design works best with a 2,2cm encoder knob. I'd recommend kilo international knobs with a number starting with 90. You could also use the [knob](/knob/) I designed for the KLOR, based on the kilo knob. 
| USB cable | 01 | For connecting the keyboard to your PC |

### OPTIONAL PARTS

| Part name | Count | Remarks | 
| :--- | :---: | :--- |
| MCU sockets | 04 | For socketing your MCU. Highly recommended |
| MCU pins | 48 | In combination with the MCU sockets |
| SK6812 Mini LED (not Mini-E) 3535 size | 42 | 40 LEDs for Konrad / 38 LEDs for Yubitsume / 36 LEDs for Saegewerk |
| [Haptic Feedback Module](https://shop.pimoroni.com/products/drv2605l-linear-actuator-haptic-breakout) | 01 | Pimoroni Haptic Buzz |
| speaker | 01 | Mallory AST1109MLTRQ or Keliking KLJ-1102 |
| [trackball](https://bit-trade-one.co.jp/selfmadekb/adtb7m/) | 01 | Pixart PAW3204OA. Available at [Yushakobo](https://shop.yushakobo.jp/products/adtb7m) |
| [level converter](https://github.com/sekigon-gonnoc/LevelConverterForTrackballModule) | 01 | Needed to use the trackball. You can get it from [Yushakobo](https://shop.yushakobo.jp/products/a0800tl-01-1/) |
| [tenting puck](https://splitkb.com/products/tenting-puck)| 02 | SplitKB Tenting Puck |

### ACRYLIC CASE PARTS

| Part name | Count | Remarks | 
| :--- | :---: | :--- |
| acrylic parts | 02 | Find the case files [here](/case/acrylic/) |
| switch plate | 02 | 1.5mm switch plate |
| 9mm M2 standoffs | 22 | Up to 22 9mm round standoffs for the actual case (check the appropriate puzzle guide) |
| 7mm M2 standoffs | 12 | 7mm round standoffs for holding the PCB in place |
| 6mm M2 screws | 56 | Up to 56 regular 6mm M2 screws (check the appropriate puzzle guide) |
| 5mm M2 wafer head screws | 12 | These screws need a flat head to fit under the acrylic top layer |

## INTRODUCTION

Here is an overview of where and on which side each component needs to be soldered (click on the image to see a larger version).

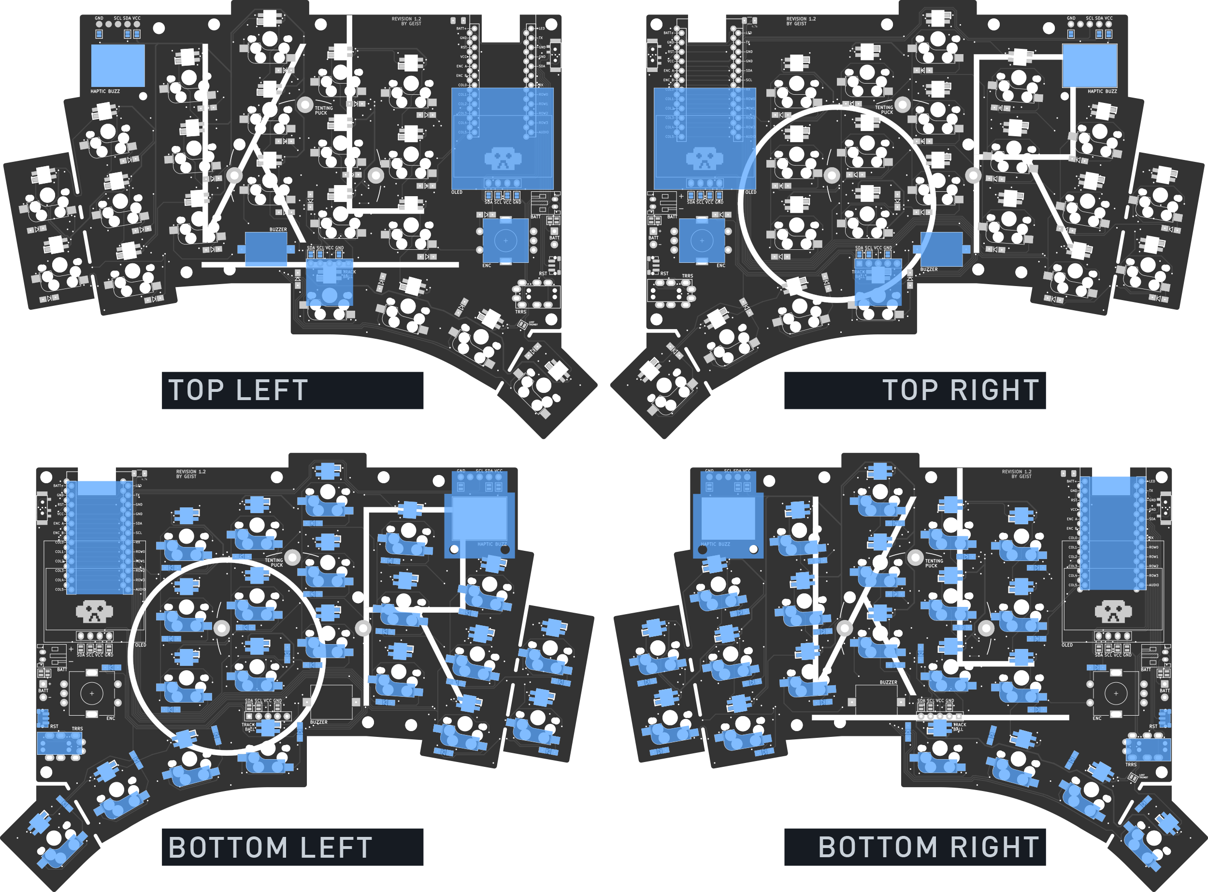
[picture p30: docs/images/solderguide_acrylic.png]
KLOR solder guide


To see what component needs to sit where you can take a look at the [interactive HTML BOM](https://htmlpreview.github.io/?https://github.com/GEIGEIGEIST/KLOR/blob/main/docs/klor_rev1-3_ibom.html).

> **Warning**
> This interactive HTML BOM does show where each component is located, but please still refer to the soldering guide above to see if a component needs to go on the top or bottom of the PCB.

Be aware that for the 3D-printed case, some components need to be soldered on the opposite side.\
Some people mark the top and bottom with tape to keep track of which side is which, as the PCB is reversible.\
Begin with the flat components and progress to the higher ones, ending with the OLEDs and the encoders.

***

## BREAK OFF PARTS (optional)

If you choose a layout [other than](/README.md#layouts) Polydactyl you should remove the unnecessary parts. Use a flush cutter to snip through the support sections. You can also use a boxcutter to carve in grooves, which makes it easier to break on the right spot. 

> **Warning**
> Be very careful with this step, since there is a risk to break the PCB. Probably it would be best to begin with this step, to avoid losing already soldered parts.

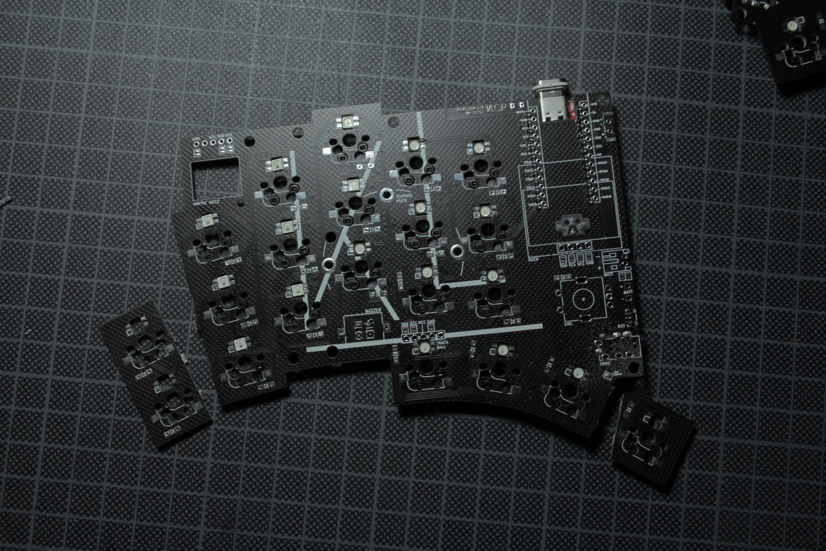
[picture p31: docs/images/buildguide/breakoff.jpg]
break off parts


You can use a file to smooth out the edges, but you should wear a mask while doing this since the FR4 dust is considered to be toxic.

***

## MICROCONTROLLER

> **Warning**
> First flash the microcontroller to make sure it works, before soldering it in.

Unlike most other boards here the microcontroller needs to be mounted on the bottom, with the components facing upwards (to the PCB).\
Feel free to use the included header pins, but it's highly recommended to use MillMax low-profile sockets.\
Place the sockets in the marked spots on the bottom side of the PCB.

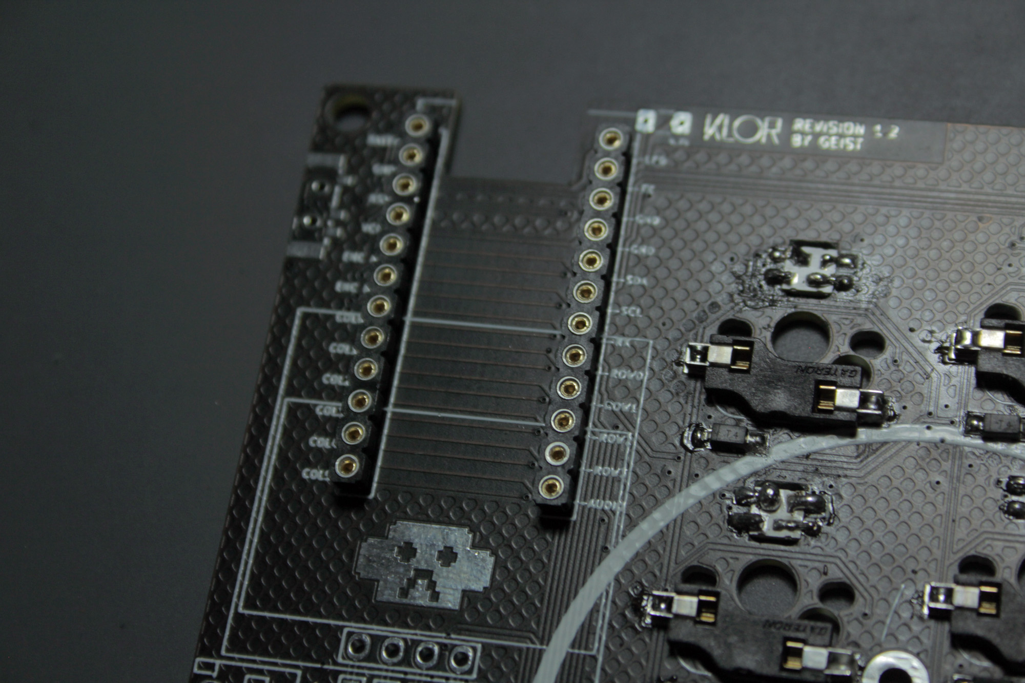
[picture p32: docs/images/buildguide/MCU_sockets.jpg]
MCU sockets


You can keep them in place by using masking tape.

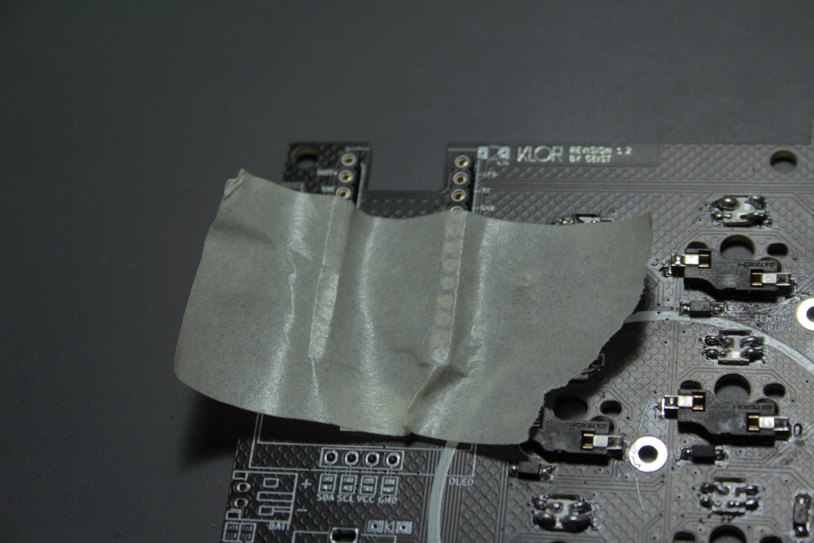
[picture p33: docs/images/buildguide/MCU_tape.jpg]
sockets taped


Then you can flip the board to solder in the sockets from the top.
Flip it again and insert the pins into the sockets.

> **Note**
> Use tweezers to insert them. Don't apply too much force, you will feel them snapping in. After that, you can carefully apply some pressure, using a flat object to make sure they're fully seated. 

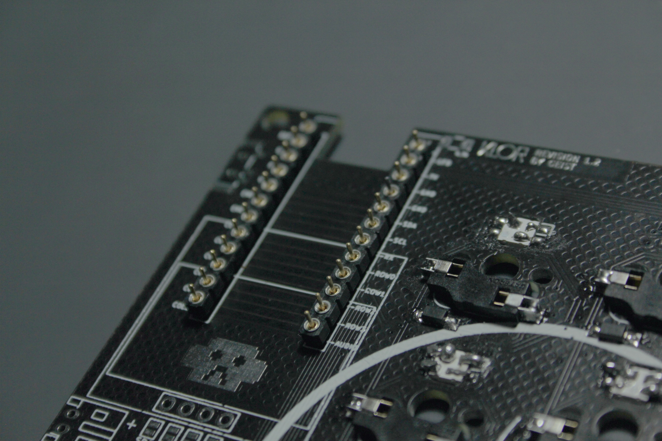
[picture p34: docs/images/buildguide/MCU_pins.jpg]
MCU pins


Now place your microcontroller on the pins (components facing the PCB) and solder it to them.\
You can use flush cutters to trim the header pins.

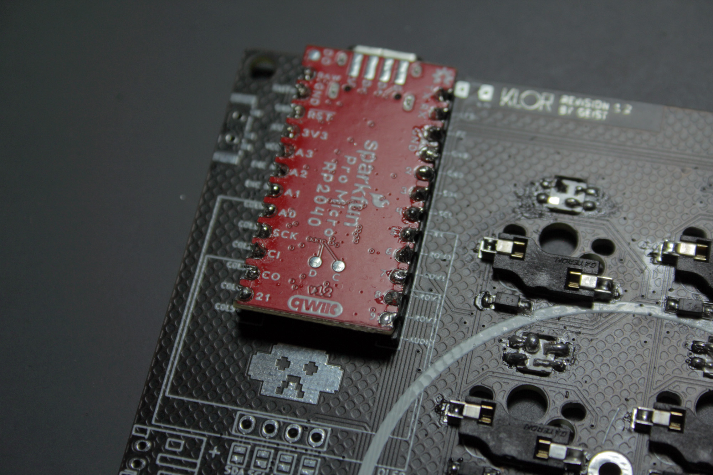
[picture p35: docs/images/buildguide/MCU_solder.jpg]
MCU solder


> **Warning**
> When trimming with flush cutters wear eye protection or hold your hand close above the pins. Otherwise, sharp metal pins flying around might hurt you.

***

## LEDS (optional)

> **Note**
> If you use a layout with three thumbs, instead of four, you need to bridge the 'lost thumb?' jumper below the TRRS sockets on the primary and secondary PCB, since the led chain lost its beginning. 

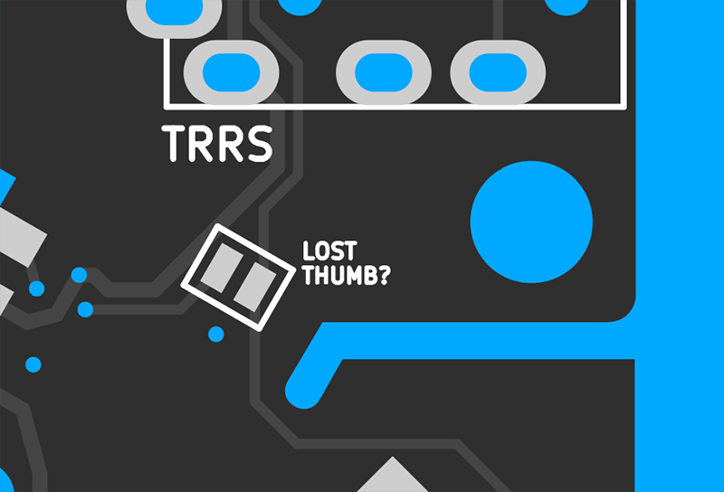
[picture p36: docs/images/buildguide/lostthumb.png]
Lost thumb jumper


LEDs are very heat sensitive. So it's a good idea to solder the pads on the PCB bottom first and then insert the LED.

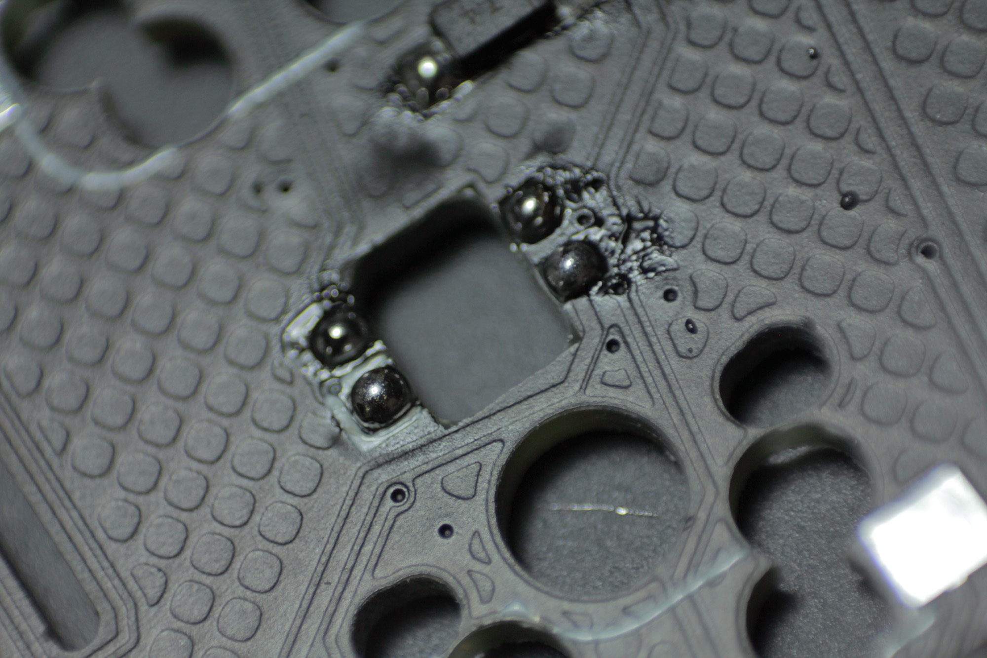
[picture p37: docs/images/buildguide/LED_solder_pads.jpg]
LED solder pads


While the bottom of the PCB is facing you, insert the LEDs in the holes. The lens should face the table.

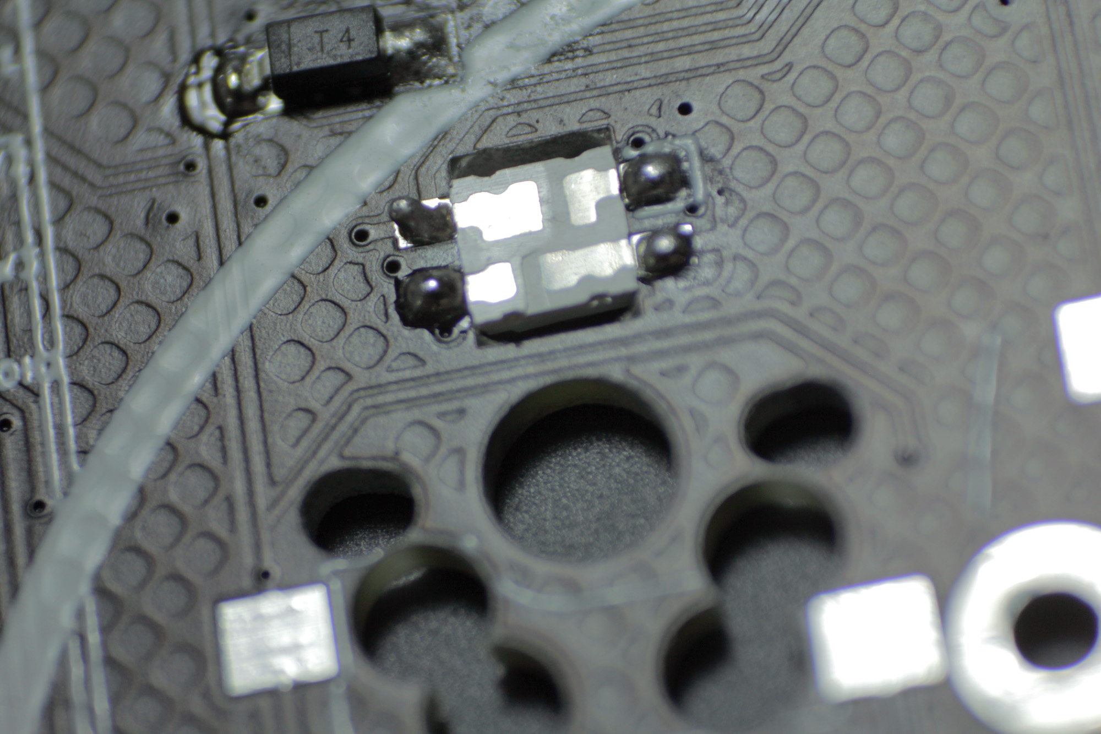
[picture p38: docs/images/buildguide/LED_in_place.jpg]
LED in place


This image depicts the correct orientation.\
The L-shaped pad on the LED needs to be connected to the square-marked pad.

LED orientation1

> **Note**
> While the orientation is uniform within one half, it differs between left and right.

> **Warning**
> It's recommended to solder the LEDs in at 220º, since they're pretty heat sensitive. Personally, I had a hard time keeping it below 270º. So my advice would be while soldering the first pad on every LED, try to be really quick. Then solder the second pad on every LED, starting with the first LED. This way they can cool down in the meantime.

Make sure the solder always builds a strong connection between the pad on the LED and the pad on the PCB. 

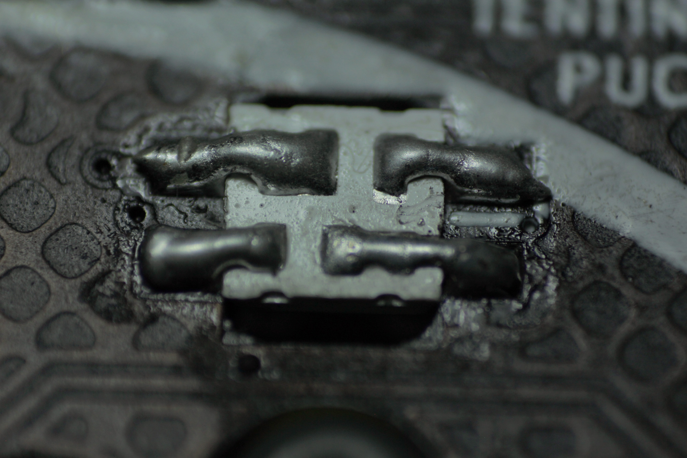
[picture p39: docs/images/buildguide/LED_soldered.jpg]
LED connection


The advantage of soldering in the microcontroller first is that you can occasionally check if all the LEDs work before continuing. 

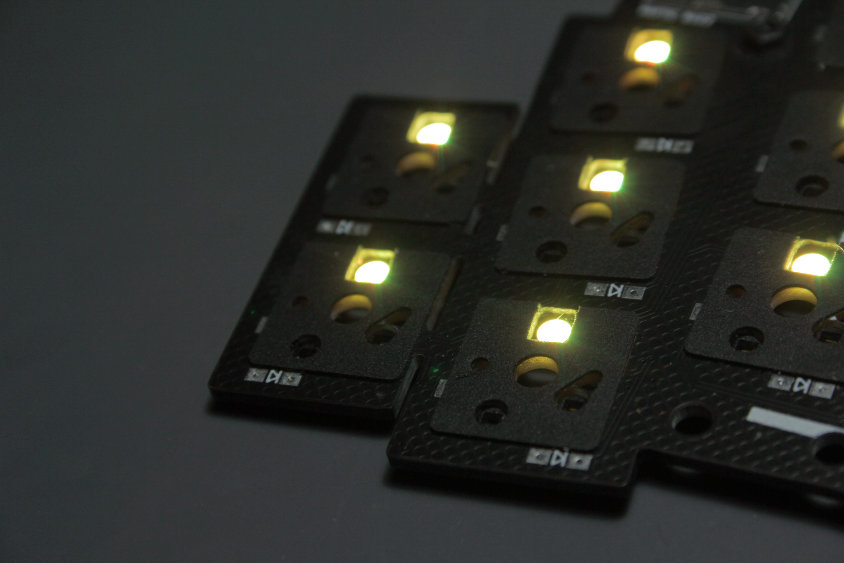
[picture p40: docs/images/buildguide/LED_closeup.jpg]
KLOR LED working


This graphic shows the order in which the LEDs are chained together.

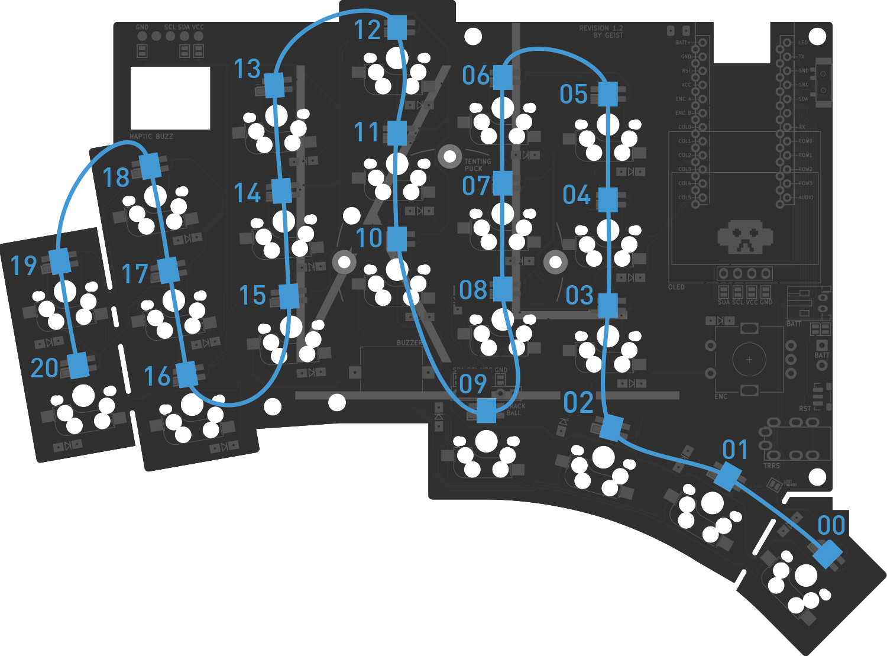
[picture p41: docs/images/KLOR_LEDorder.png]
KLOR LED order


***

## DIODES

The diodes need to be soldered on the bottom of the PCB. Pay attention to their orientation:  They have a small line on one side, which should be on the side the arrow on the PCB is facing to.

<p align="center">
<picture>
  <source media="(prefers-color-scheme: dark)" srcset="/docs/images/buildguide/diodes_dark.svg">
  <source media="(prefers-color-scheme: light)" srcset="/docs/images/buildguide/diodes_bright.svg">
  diode orientation
</picture>
</p>

Apply a small amount of solder on one pad.

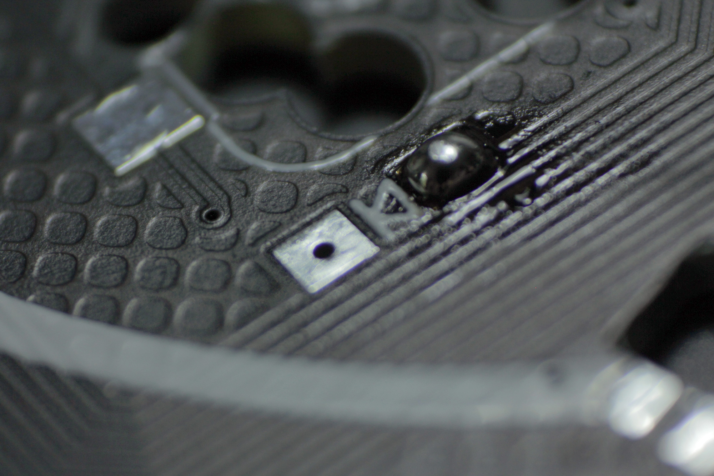
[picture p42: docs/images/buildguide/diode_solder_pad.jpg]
Solder on one pad


Then use tweezers to place the diode on the pads and reheat the solder to secure the diode.

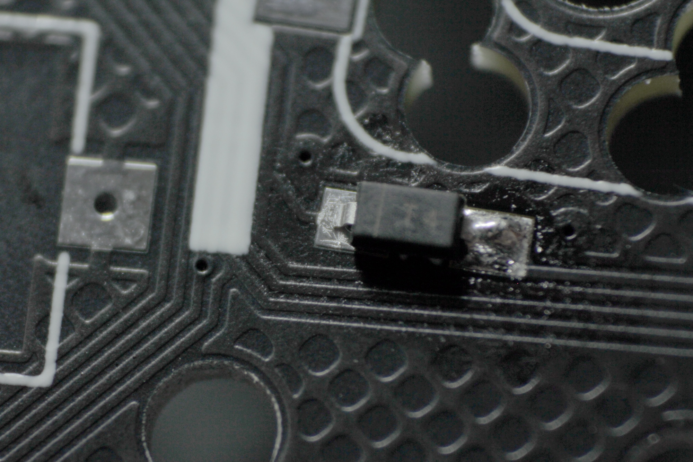
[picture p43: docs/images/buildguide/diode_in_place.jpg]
Solder diode


Now you can solder the second pad.

***

## SWITCH SOCKETS

Here you can apply the same technique as used for the diodes: Apply some solder on one of the pads first.

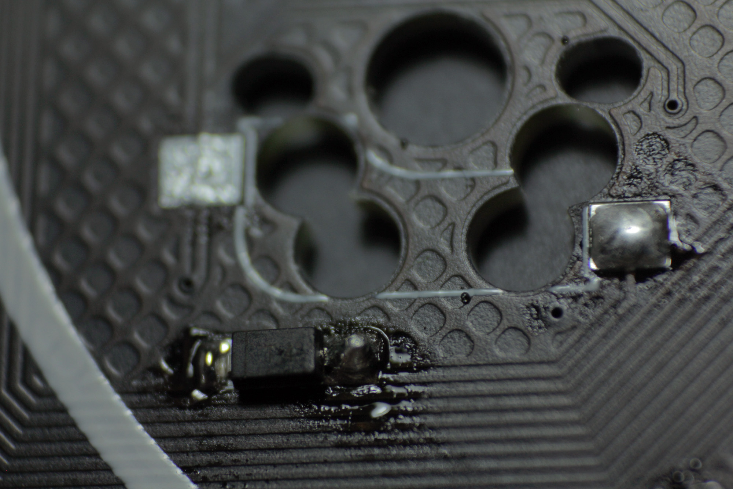
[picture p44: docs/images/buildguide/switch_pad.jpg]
switch sockets pad


Then place the switch socket in the silk screen markings and reheat the solder. Apply some pressure with a pair of tweezers to make sure the socket is fully seated.\
Now solder the second pad.

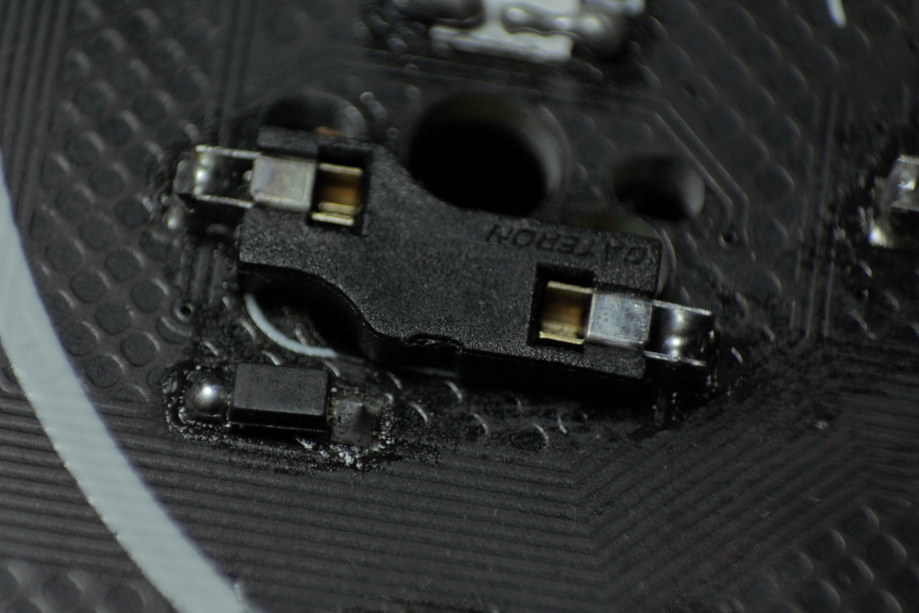
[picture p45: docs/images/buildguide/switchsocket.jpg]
switch socket soldered


***

## RESET SWITCHES

The reset switches are a bit fiddly to solder. It helps to apply a really thin film of solder to the outer pads first. Then hold the switch in place with tweezers and solder the big pads on the left and right of the switch (they do not fulfill any electrical purpose, but serve to hold the switches in place). If the switch is seated correctly flip the PCB and solder the pads in the middle from below.

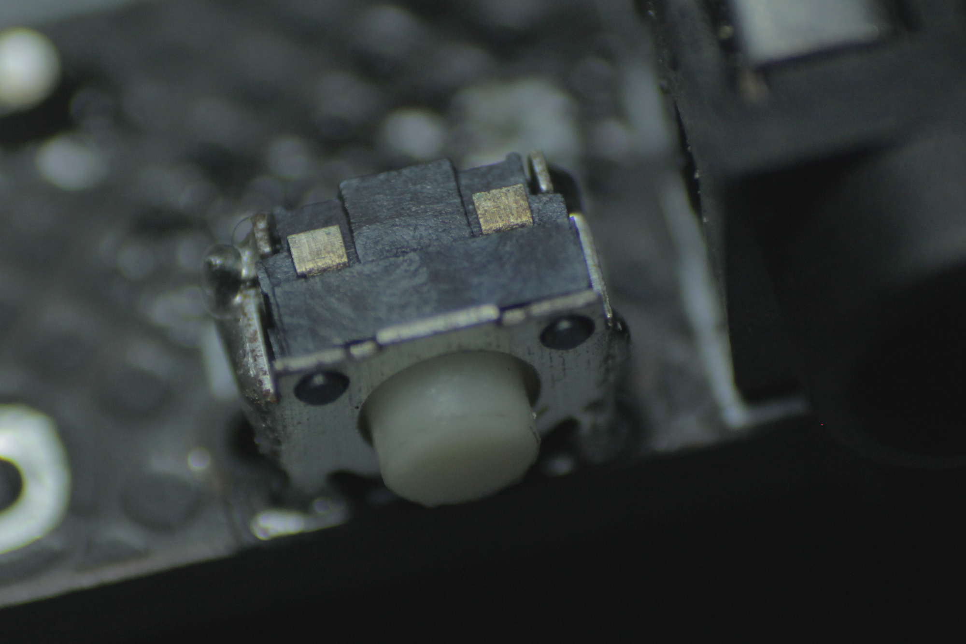
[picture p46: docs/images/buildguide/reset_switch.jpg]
reset switch


***

## TRRS JACKS

Install the TRRS jack on the bottom side of the PCB. The place where you should insert it is marked with a white line.
You may want to use some masking tape to hold it in place since you need to solder it on the bottom.

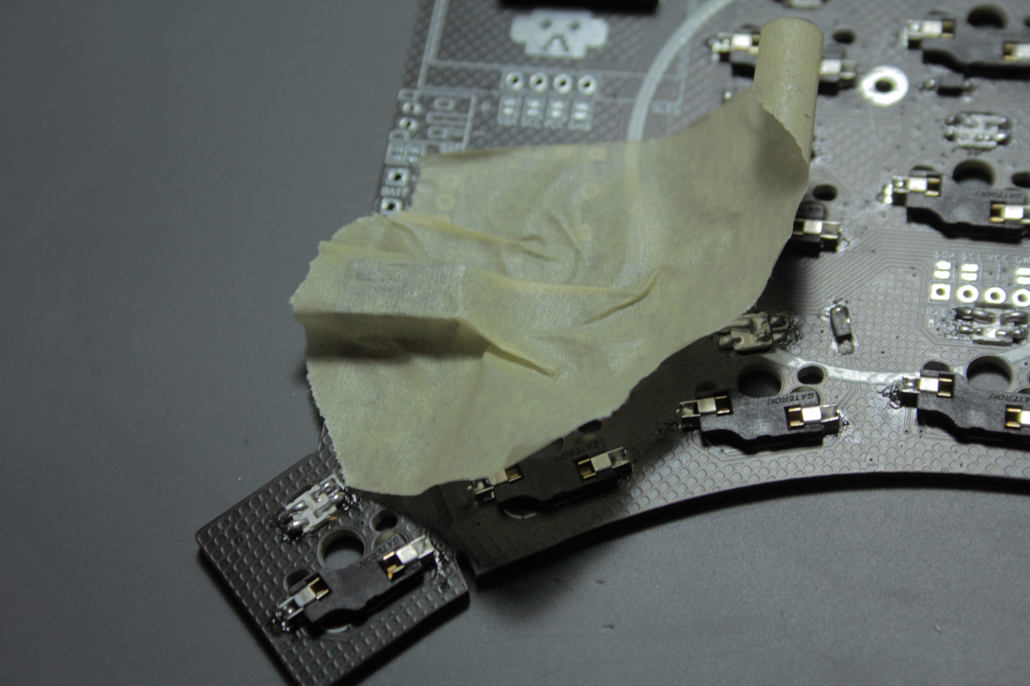
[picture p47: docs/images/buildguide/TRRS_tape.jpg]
TRRS jack taped


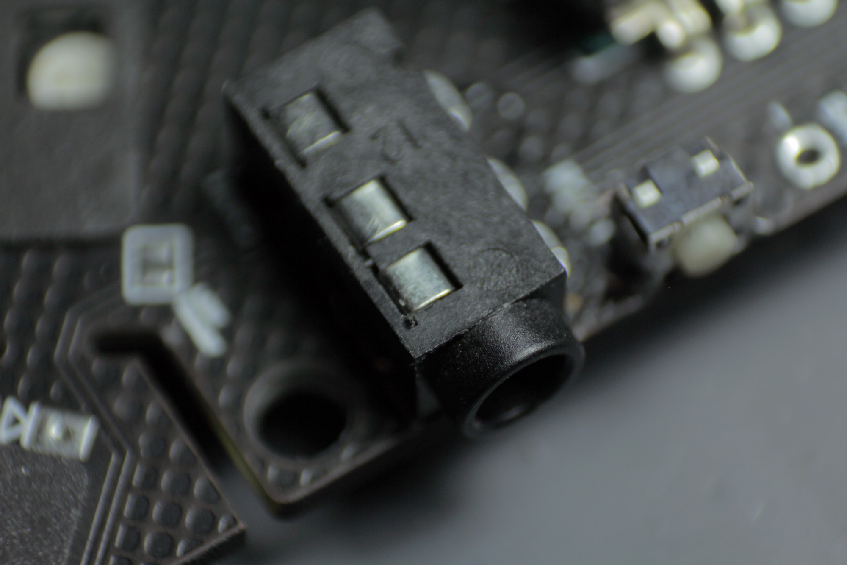
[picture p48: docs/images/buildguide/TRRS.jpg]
TRRS jack soldered


***

## HAPTIC FEEDBACK (optional)

> **Note**
> Currently, haptic feedback only works on the primary side of your keyboard, which is a limitation of QMK.

Apply some solder to the jumpers on the top to bridge them.

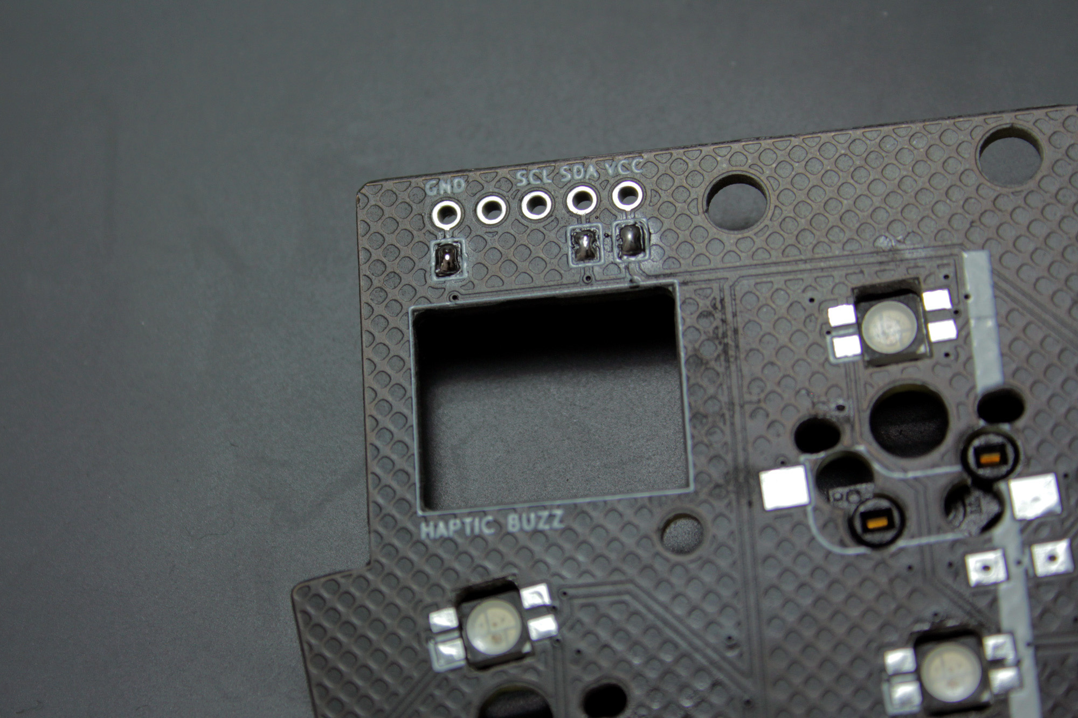
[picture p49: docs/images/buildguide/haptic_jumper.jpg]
haptic feedback Jumper


Insert the module from below with the motor facing upwards. Then insert the pin headers from below.

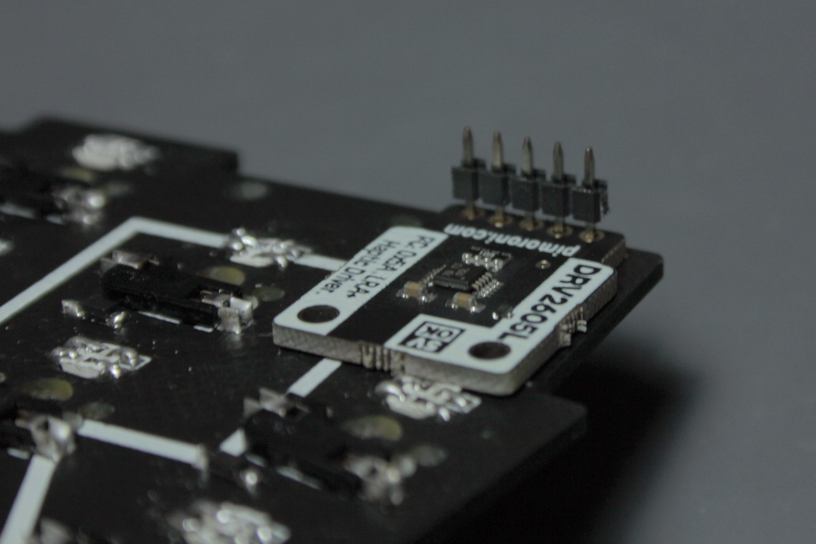
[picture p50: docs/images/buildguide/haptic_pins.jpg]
haptic feedback pins


Now you can solder the pins and use a flush cutter to snap off the excess. Remember to hold your hand above them or wear eye protection while doing so.

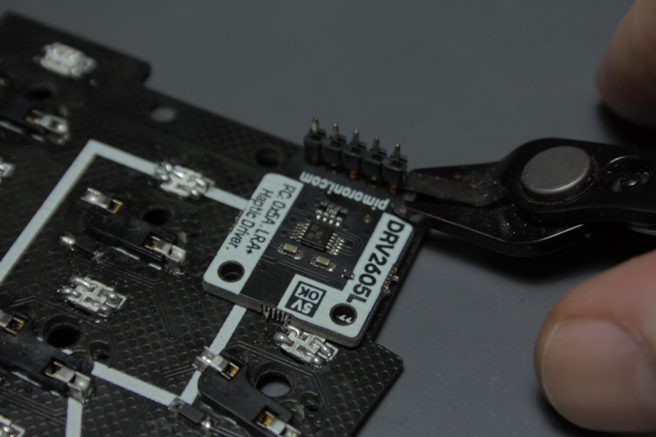
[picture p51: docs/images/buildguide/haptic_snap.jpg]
haptic feedback snap of pins


You can also use a screw and a nut to stabilize the module further. But this step is optional.

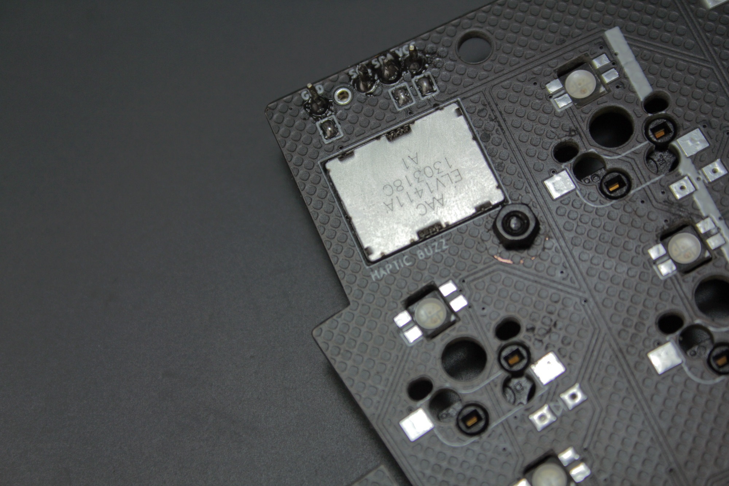
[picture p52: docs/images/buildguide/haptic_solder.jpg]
haptic feedback solder


***

## SPEAKER (optional)

> **Note**
> Currently haptic feedback only works on the primary side of your keyboard, which is a limitation of QMK. Unfortunately, the audio feature of QMK doesn't work yet with the RP2040.

Soldering the speaker is pretty simple. Apply a tiny bit of solder on one of the pads, use tweezers to hold the speaker in place, and reheat the solder. After that apply solder to the other pad.

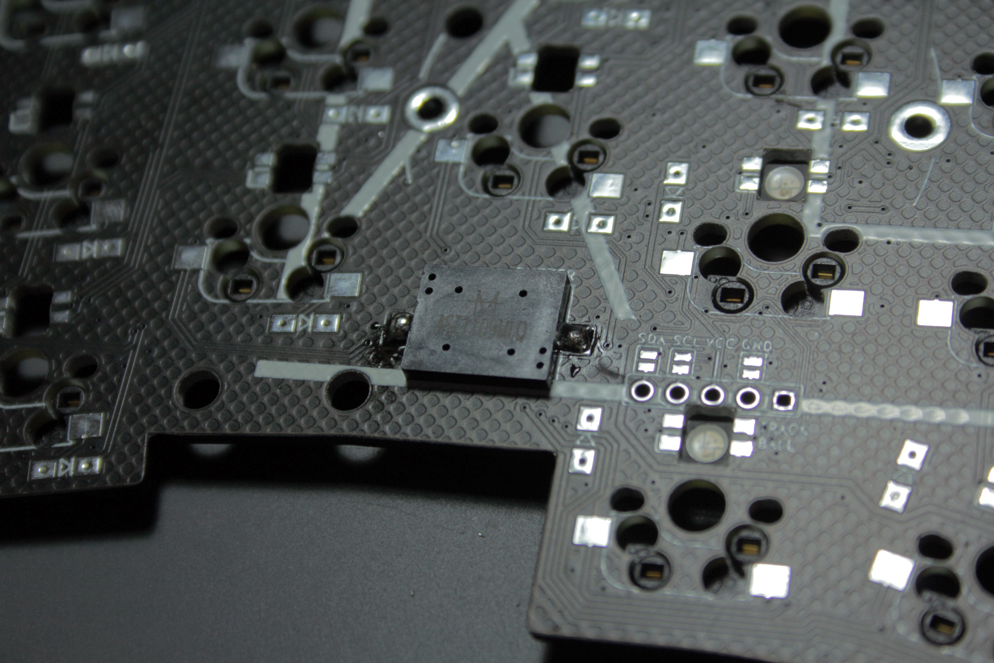
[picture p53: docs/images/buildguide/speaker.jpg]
speaker


***

## TRACKBALL (optional)
> **Note**
> While the hardware side should already work fine, I still need to add the code for the trackball.

TBA

***

## ENCODERS

Mount the rotary encoder on the top side of the PCB. It should click into place maybe requiring a firm press. If it's seated correctly solder the pins on the bottom.

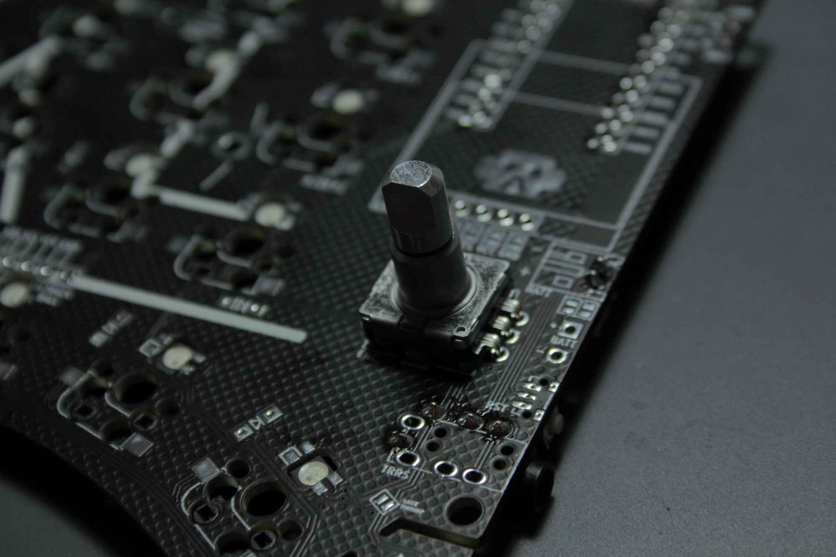
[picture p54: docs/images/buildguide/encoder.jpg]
encoder


***

## OLEDs

> **Warning**
> Make sure the keyboard is fully functional before soldering the OLEDs, since they're the only components that cover pins, you won't be able to access them once they are in place.

The first step should be to bridge the jumpers on the top of the PCB next to the OLED.

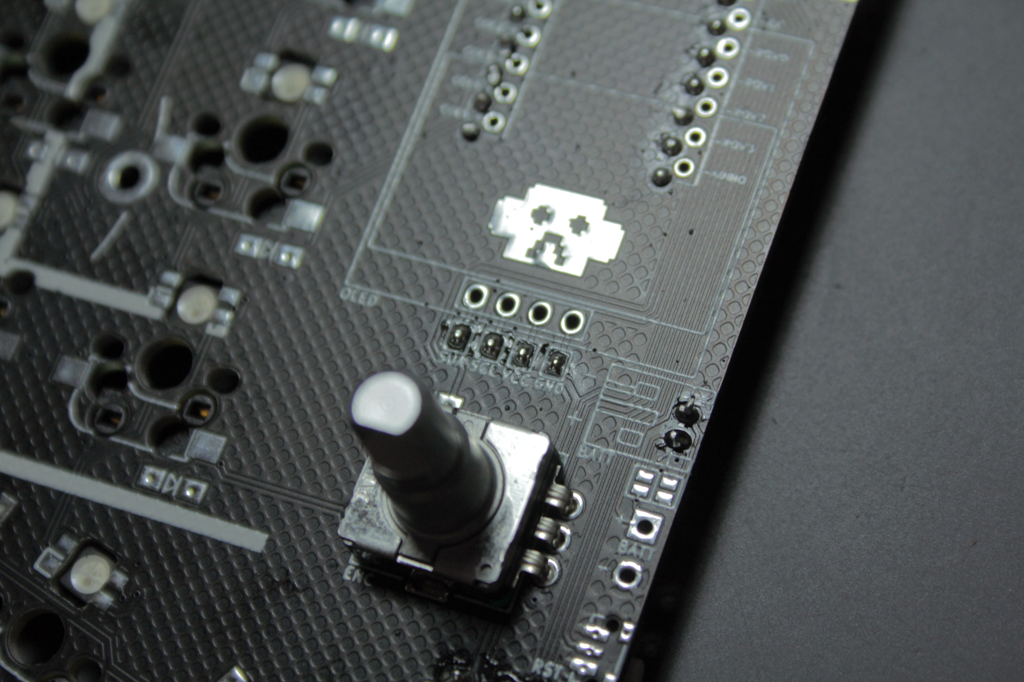
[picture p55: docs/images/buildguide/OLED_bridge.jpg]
OLED bridge jumpers


> **Note**
> The OLED needs to be as flush to the PCB as possible to fit under the switchplate.

You need to remove the plastic part, which is usually attached to the OLED, from the headers, while keeping the pins. For me the easiest way is to use flush cutters to snap the plastic in half, which allows you to remove the parts easily. You probably need to bend the pins back in place after doing this.

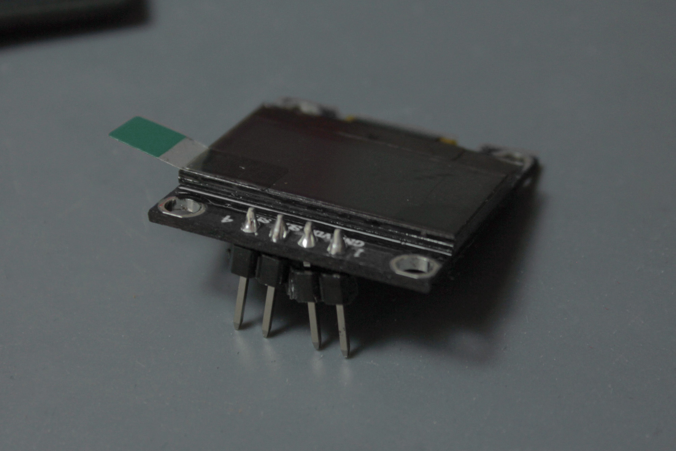
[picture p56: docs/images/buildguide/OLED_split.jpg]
OLED pin split


You also need to cover the back of the OLED with electrical tape, to prevent shorts with the microcontroller pins. Especially the top part with the copper traces is important.

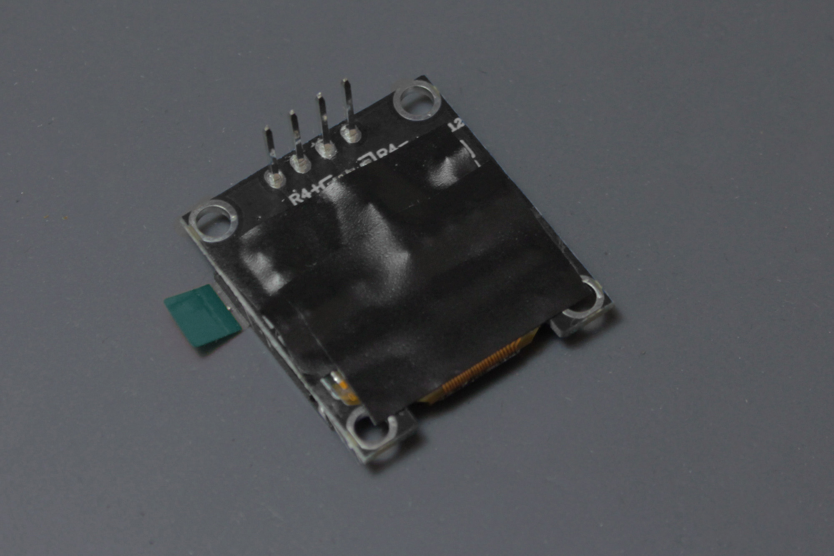
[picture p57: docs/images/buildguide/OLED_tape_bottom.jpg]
OLED tape on bottom


Insert the OLED on the top of the PCB. Make sure it sits as flush with the PCB as possible. Maybe hold it in place with some masking tape.

> **Note**
> You could also temporarily install the switchplate over the OLED, using a few switches. This way you make sure it's exactly in the right spot and rotation.

Solder the OLED into place.

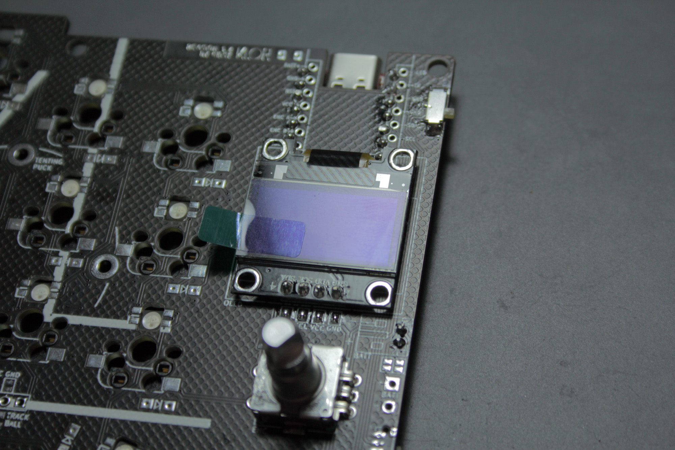
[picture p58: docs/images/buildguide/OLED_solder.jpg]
OLED soldering


Now use flush cutters to trim the top and bottom pins. Especially the top pins should be as short as possible to avoid interference with the switch plate.

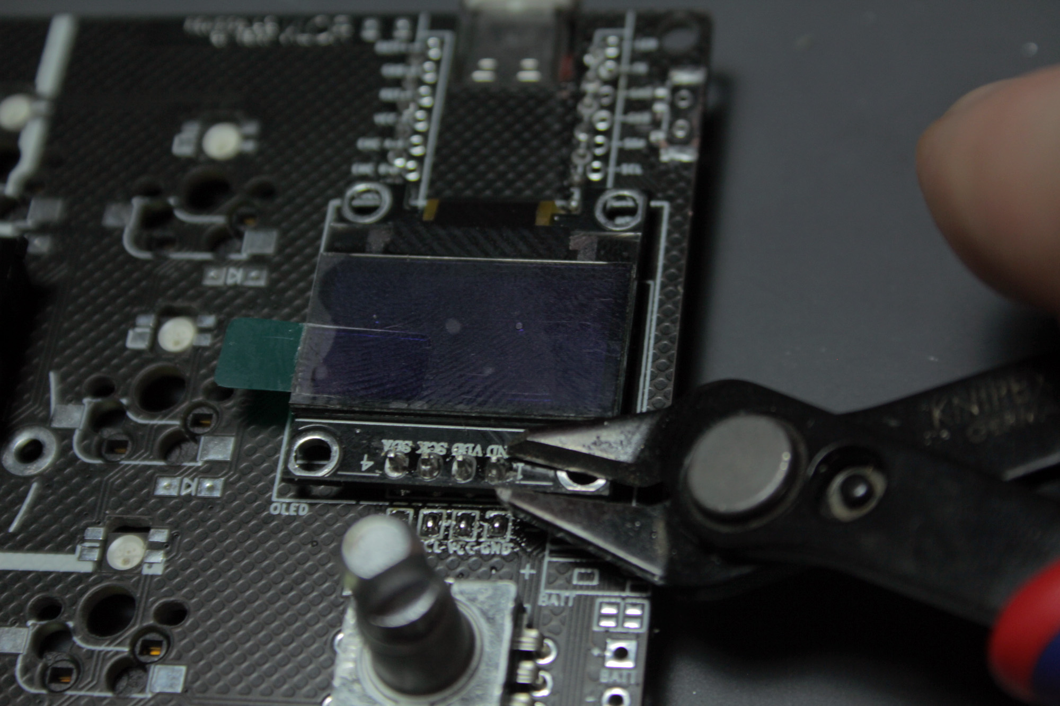
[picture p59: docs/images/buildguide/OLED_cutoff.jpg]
OLED flush cutter


If you use a metal switch plate consider covering them with electrical tape to prevent shorts.

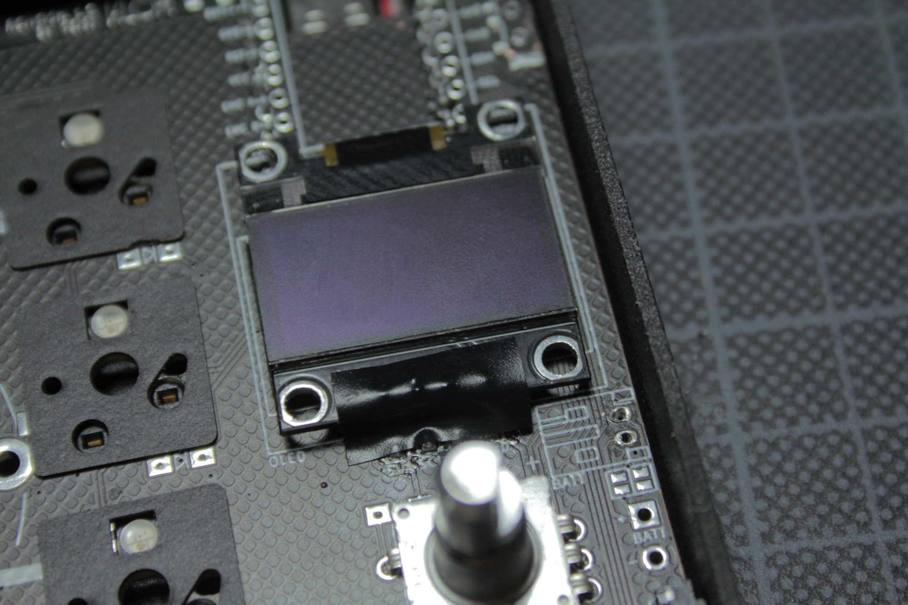
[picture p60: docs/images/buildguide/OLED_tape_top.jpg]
OLED tape on top


> **Note**
> If you need to desolder the OLED or fix its placement just apply a lot of solder to the four pins to connect them. This way you can heat all four pins at once and remove them by gently applying force to the bottom edge of the OLED module. Be really careful not to use too much pressure, since you could rip off a pad or destroy the OLED (which happens pretty fast).

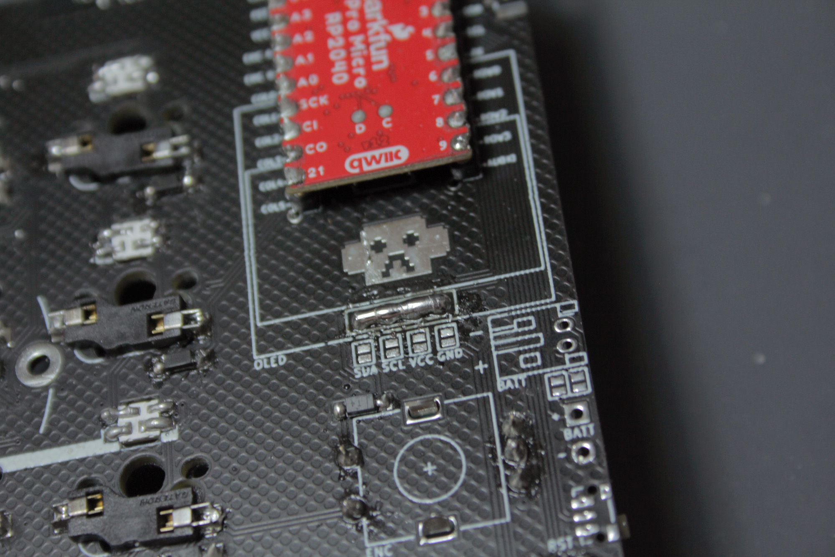
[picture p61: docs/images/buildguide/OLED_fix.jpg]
OLED desolder


***

## CLEANING

This is what your finished PCB probably will look like. You can use an old toothbrush and some isopropanol to clean it from residues. 

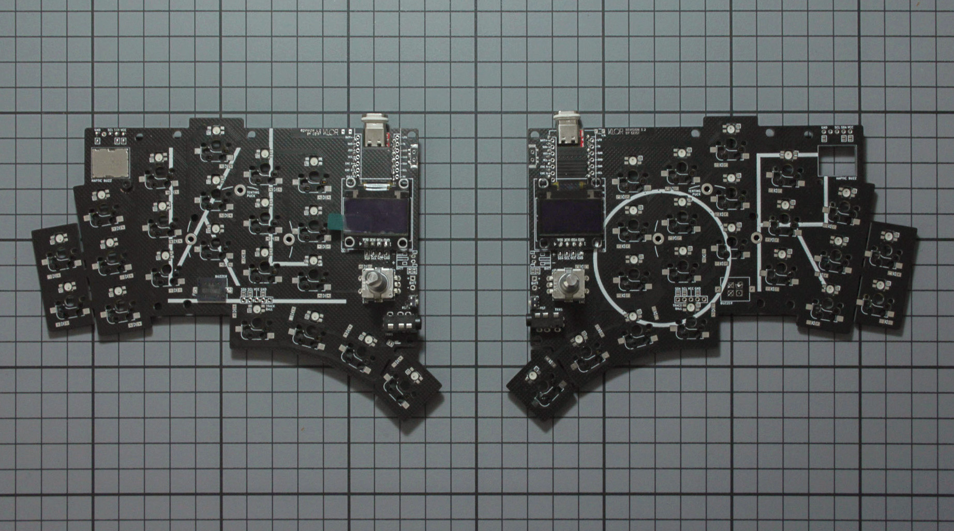
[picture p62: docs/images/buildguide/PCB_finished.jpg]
Finished PCB

***IMAGE***

***

## FIRMWARE

### AVR-based ProMicro 
**e.g. Pro Micro / Elite-C / Puchi-C**

If you have not already flashed the firmware to the microcontroller you should do it now, to make sure everything works, before inserting it into the case.\
[Here](https://github.com/GEIGEIGEIST/qmk-config-klor) you can find the QMK firmware for the KLOR.\
Copy the **klor** folder into the **keyboards** directory of your qmk installation.\
Then use [QMK MSYS](https://msys.qmk.fm/) (or the command line tool of your choice) to compile it with this command:

``qmk compile -kb klor -km default`` 

This will create a file called **klor_default.hex** in your **qmk_firmware** folder.\
Open [QMK Toolbox](https://github.com/qmk/qmk_toolbox) and locate the **klor_default.hex** file.\
Connect the ProMicro/keyboard and press the reset button (or connect the RST and GND pins on the ProMicro). QMK toolbox should show a connected device.\
Press **flash** in QMK toolbox to flash the firmware on your microcontroller.

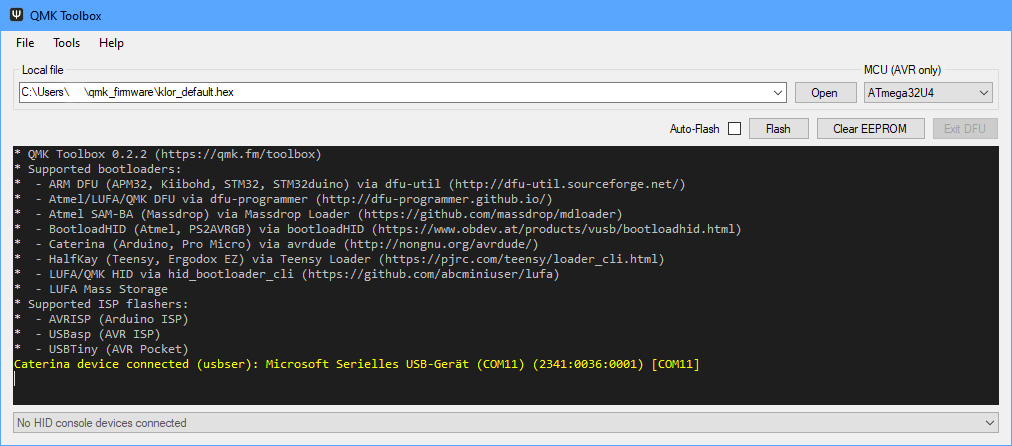
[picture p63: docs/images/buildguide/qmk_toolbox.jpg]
QMK toolbox


### RP2040 ProMicro 
**e.g. Adafruit KB2040 / Sparkfun Pro Micro RP2040 / Boardsource Blok / Elite-Pi / Sea-Picro**

Copy the **klor** folder into the **keyboards** directory of your qmk installation.\
Then use [QMK MSYS](https://msys.qmk.fm/) (or the command line tool of your choice) to compile it with this command:

``qmk compile -kb klor/rp2040 -km default``

This will create a file called **klor_rp2040_default.uf2** in your **qmk_firmware** folder.\
The first time you need to keep boot pressed, then press reset and release boot. This will open the flash memory of your MicroController as a device in your OS.\
Copy the **klor_rp2040_default.uf2** there to flash it. 

> **Note**
> After flashing the firmware the first time you can access the flash memory by double pressing the reset button on your keyboard or define a software reset key by using **QK_boot** as keycode.

***

## STACKED ACRYLIC CASE

> **Note**
> Since there are a lot of different parts please check the 'puzzle guide' which you can find in the same folder as the case files of your layout. 

Screw the standoffs onto the bottom plate. You can find the location of the 7mm standoffs and 9mm standoffs in the 'puzzle guide', but as a rule of thumb, the 9mm standoffs should be on the outside, holding the case parts, while the 7mm standoffs will hold the PCB and switchplate.\
(The dark shapes on the bottom are pieces of deskmat, I use as bumpers.) 

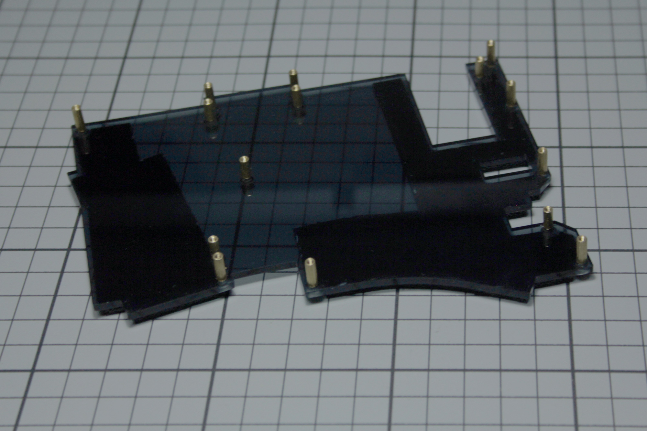
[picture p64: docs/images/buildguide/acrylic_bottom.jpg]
acrylic bottom


Next, you should align the parts of the first layer to the outer standoffs. The parts for the left and right cases are interchangeable.

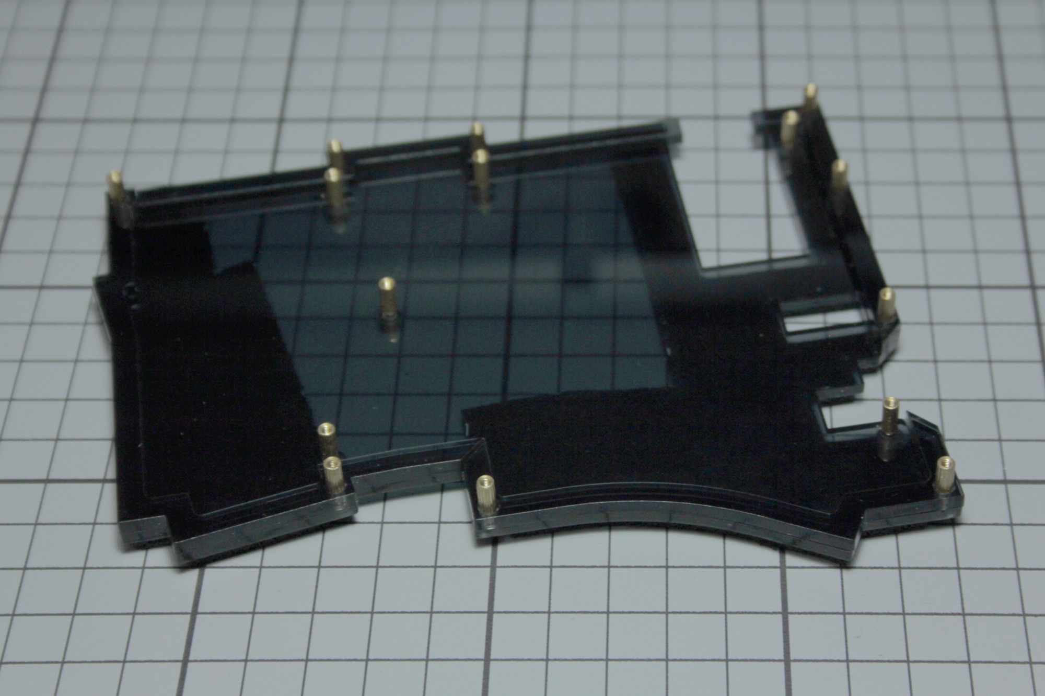
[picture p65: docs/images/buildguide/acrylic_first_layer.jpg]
acrylic first layer


Now you can insert the PCB and add the other layers.

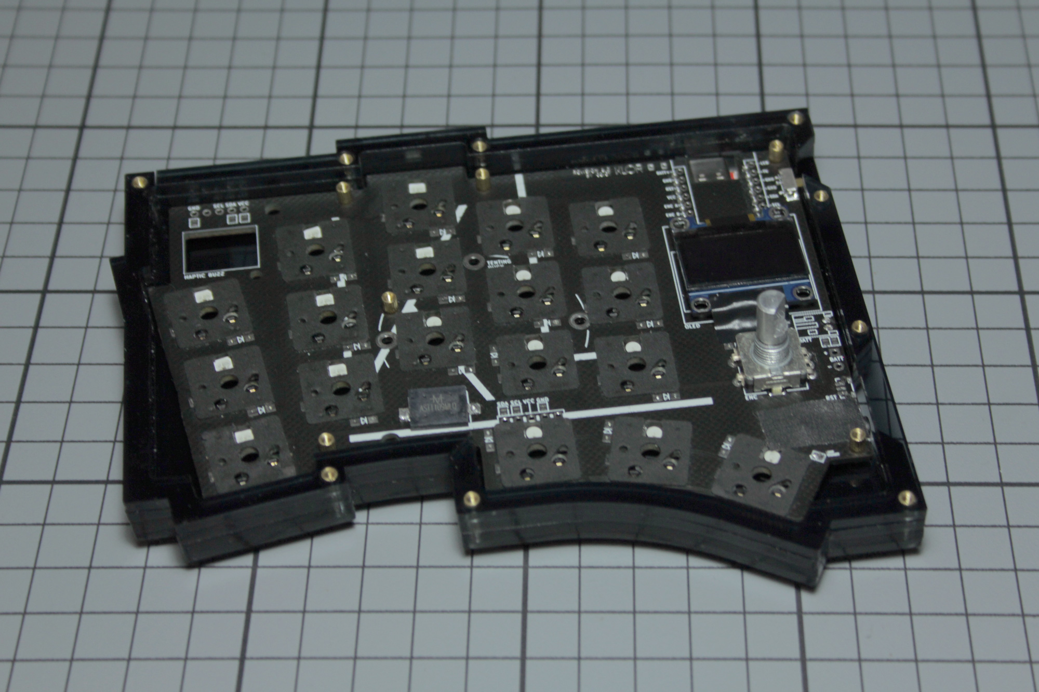
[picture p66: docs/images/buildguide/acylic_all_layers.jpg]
acrylic all layers


 Align the plate and screw them to the center standoffs.

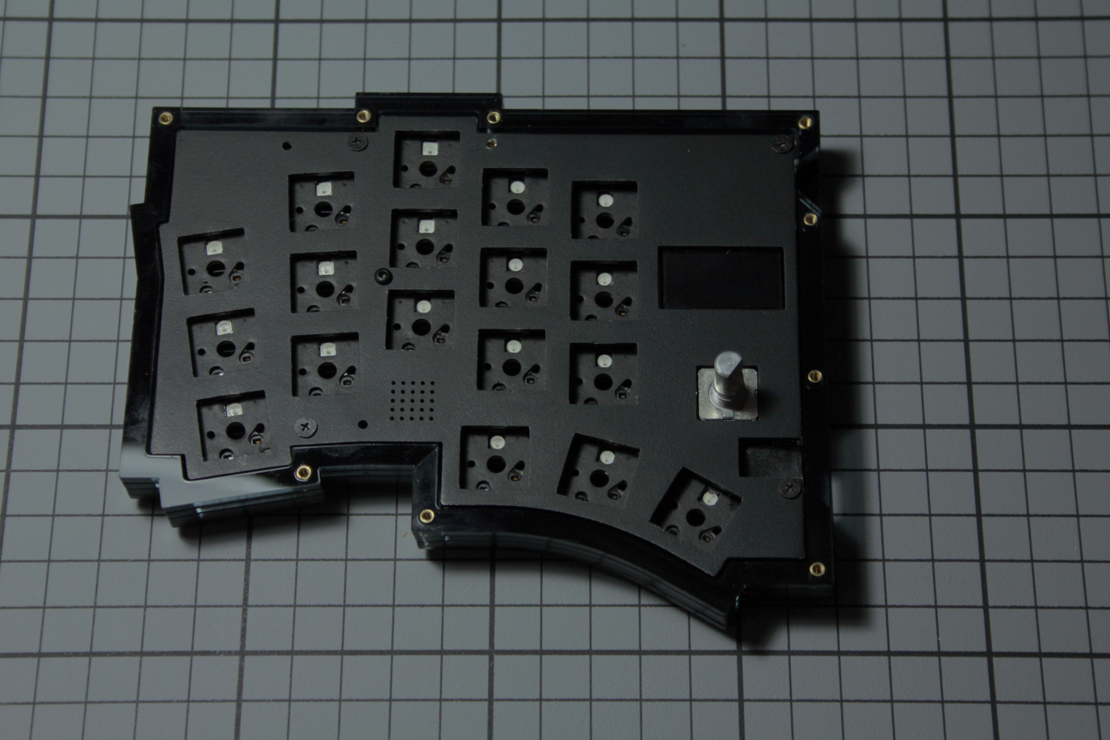
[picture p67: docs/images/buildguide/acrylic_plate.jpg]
acrylic switchplate
 

For this step, you need the 5mm wafer head screws, since other screwheads would intersect with the top layer.

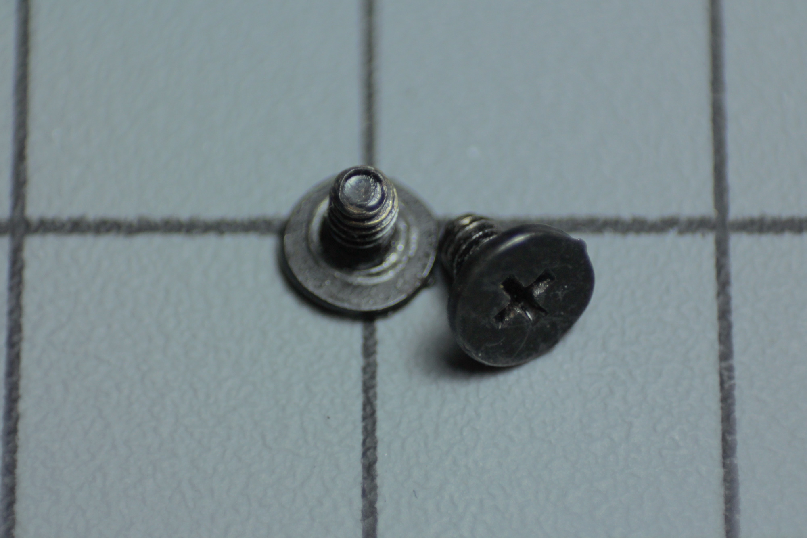
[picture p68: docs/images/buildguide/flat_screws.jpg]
wafer head screws


Finally, attach the top plate and insert the switches into the plate.

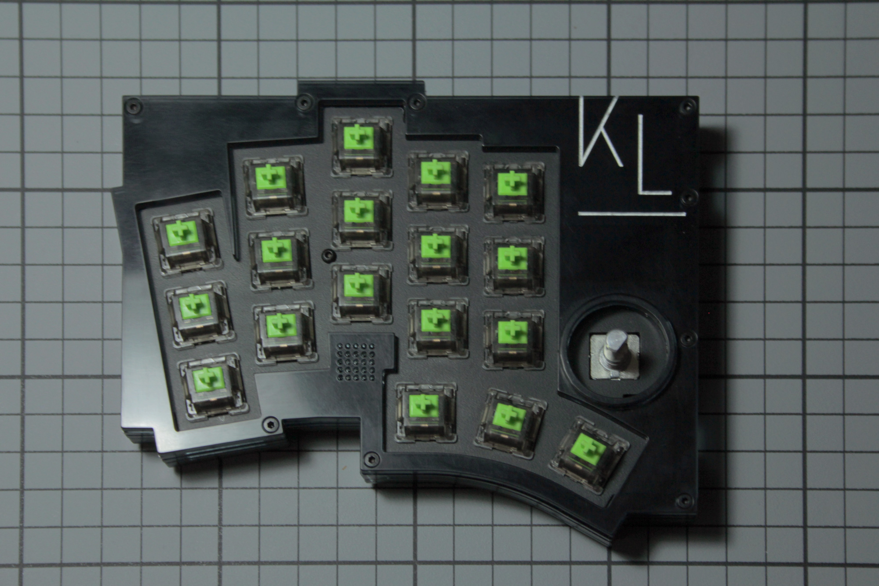
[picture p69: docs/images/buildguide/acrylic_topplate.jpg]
acrylic top plate


***

## KNOBS

The design works best with 23mm (0.9") diameter encoder knobs. My recommendation would be a knob from kilo international with a number beginning with 90 (which means a 0.9" diameter) like the OEDNI-90-4-7 shown here.

OEDNI-90-4-7

***

## FINAL BUILD

This is how the final keyboard will look like. In this picture you see the KLOR saegewerk, with RAMA Grid keycaps in NOCT.

KLOR acrylic case

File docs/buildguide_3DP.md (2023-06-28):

# KLOR BUILD GUIDE (3DP CASE) [WIP]

## PART LIST

### REQUIRED PARTS

| Part name | Count | Remarks | 
| :--- | :---: | :--- |
| KLOR PCB | 02 | You can find the files for it [here](/PCB/) |
| ProMicro | 02 | Alternatively, you can use another controller with a similar pinout like the Elite-C, Puchi-C, KB2040 dda. |
| MX Key switch | 42 | 40 switches for Konrad / 38 switches for Yubitsume / 36 switches for Saegewerk |
| switch socket | 42 | 40 sockets for Konrad / 38 sockets for Yubitsume / 36 sockets for Saegewerk |
| diodes 1N4148W| 44 | These are surface mount diodes in SOD123 package. 42 for Konrad / 40 for Yubitsume / 38 for Saegewerk |
| 1u MX keycaps | 42 | 40 keycaps for Konrad / 38 keycaps for Yubitsume / 36 keycaps for Saegewerk |
| OLED module | 02 | SSD1306 128x64 pixel OLED Displays |
| reset button  | 02 | Alps SKRTLAE010 |
| TRRS jack | 02 | MJ-4PP-9 or PJ320A |
| TRRS cable | 01 | Alternatively, you can use a TRS cable for [half-duplex](https://github.com/qmk/qmk_firmware/blob/master/docs/serial_driver.md#usart-half-duplex)|
| EC11 encoder  | 02 | You can use any EC11 encoder, but it will look better if you use a short one, like the EC11N1524402 |
| encoder knob  | 02 | The design works best with a 2,2cm encoder knob. I'd recommend kilo international knobs with a number starting with 90. You could also use the [knob](/knob/) I designed for the KLOR, based on the kilo knob. 
| USB cable | 01 | For connecting the keyboard to your PC |

### OPTIONAL PARTS

| Part name | Count | Remarks | 
| :--- | :---: | :--- |
| MCU sockets | 04 | For socketing your MCU. Highly recommended |
| MCU pins | 48 | In combination with the MCU sockets |
| SK6812 Mini LED (not Mini-E) 3535 size | 42 | 40 LEDs for Konrad / 38 LEDs for Yubitsume / 36 LEDs for Saegewerk |
| [Haptic Feedback Module](https://shop.pimoroni.com/products/drv2605l-linear-actuator-haptic-breakout) | 01 | Pimoroni Haptic Buzz |
| speaker | 01 | Mallory AST1109MLTRQ or Keliking KLJ-1102 |
| [trackball](https://bit-trade-one.co.jp/selfmadekb/adtb7m/) | 01 | Pixart PAW3204OA. Available at [Yushakobo](https://shop.yushakobo.jp/products/adtb7m) |
| [level converter](https://github.com/sekigon-gonnoc/LevelConverterForTrackballModule) | 01 | Needed to use the trackball. You can get it from [Yushakobo](https://shop.yushakobo.jp/products/a0800tl-01-1/) |
| [tenting puck](https://splitkb.com/products/tenting-puck)| 02 | SplitKB Tenting Puck |

### 3DP CASE PARTS

| Part name | Count | Remarks | 
| :--- | :---: | :--- |
| 3D printed case | 02 | Find the case files [here](/case/3DP) |
| acrylic parts | 02 | Three parts and one ring per side |
| switch plate | 02 | 1.5mm switch plate |
| 7mm M2 standoffs | 16 | round |
| 6mm M2 screws | 16 | |
| 6mm M2 countersunk screws | 16 | The bottom only supports countersunk screws |

## INTRODUCTION

Here is an overview of where and on which side each component needs to be soldered (click on the image to see a larger version).

KLOR solder guide

To see what component needs to sit where you can take a look at the [interactive HTML BOM](https://htmlpreview.github.io/?https://github.com/GEIGEIGEIST/KLOR/blob/main/docs/klor_rev1-3_ibom.html).

> **Warning**
> This interactive HTML BOM does show where each component is located, but please still refer to the soldering guide above to see if a component needs to go on the top or bottom of the PCB.

Be aware that for the stacked acrylic case some components need to be soldered on the opposite side.\
Some people mark the top and bottom with tape to keep track of which side is which, as the PCB is reversible.\
Begin with the flat components and progress to the higher ones, ending with the OLEDs and the encoders.

***

## BREAK OFF PARTS (optional)

If you choose a layout [other than](/README.md#layouts) Polydactyl you should remove the unnecessary parts. Use a flush cutter to snip through the support sections. You can also use a boxcutter to carve in grooves, which makes it easier to break on the right spot. 

> **Warning**
> Be very careful with this step, since there is a risk to break the PCB. Probably it would be best to begin with this step, to avoid losing already soldered parts.

break off parts

You can use a file to smooth out the edges, but you should wear a mask while doing this since the FR4 dust is considered to be toxic.

***

## MICROCONTROLLER

> **Warning**
> First flash the microcontroller to make sure it works, before soldering it in.

Unlike most other boards here the microcontroller needs to be mounted on the bottom, with the components facing upwards (to the PCB).\
Feel free to use the included header pins, but it's highly recommended to use MillMax low-profile sockets.\
Place the sockets in the marked spots on the bottom side of the PCB.

MCU sockets

You can keep them in place by using masking tape.

sockets taped

Then you can flip the board to solder in the sockets from the top.
Flip it again and insert the pins into the sockets.

> **Note**
> Use tweezers to insert them. Don't apply too much force, you will feel them snap in. After that, you can carefully apply some pressure, using a flat object to make sure they're fully seated. 

MCU pins

Now place your microcontroller on the pins (components facing the PCB) and solder it to them.\
You can use flush cutters to trim the header pins.

MCU solder

> **Warning**
> When trimming with flush cutters wear eye protection or hold your hand close above the pins. Otherwise, sharp metal pins flying around might hurt you.

***

## LEDS (optional)

> **Note**
> If you use a layout with three thumbs, instead of four, you need to bridge the 'lost thumb?' jumper below the TRRS sockets on the primary and secondary PCB, since the led chain lost its beginning. 

Lost thumb jumper

LEDs are very heat sensitive. So it's a good idea to solder the pads on the PCB bottom first and then insert the LED.

LED solder pads

While the bottom of the PCB is facing you, insert the LEDs in the holes. The lens should face the table.

LED in place

This image depicts the correct orientation.\
The L-shaped pad on the LED needs to be connected to the square-marked pad.

LED orientation1

> **Note**
> While the orientation is uniform within a half, it differs between left and right.

> **Warning**
> It's recommended to solder the LEDs in at 220º since they're pretty heat sensitive. Personally, I had a hard time keeping it below 270º. So my advice would be while soldering the first pad on every LED, try to be really quick. Then solder the second pad on every LED, starting with the first LED. This way they can cool down in the meantime.

Make sure the solder always builds a strong connection between the pad on the LED and the pad on the PCB. 

LED connection

The advantage of soldering in the microcontroller first is that you can occasionally check if all the LEDs work before continuing. 

KLOR LED working

This graphic shows the order in which the LEDs are chained together.

KLOR LED order

***

## DIODES

The diodes need to be soldered on the bottom of the PCB. Pay attention to their orientation:  They have a small line on one side, which should be on the side the arrow on the PCB is facing to.

<p align="center">
<picture>
  <source media="(prefers-color-scheme: dark)" srcset="/docs/images/buildguide/diodes_dark.svg">
  <source media="(prefers-color-scheme: light)" srcset="/docs/images/buildguide/diodes_bright.svg">
  diode orientation
</picture>
</p>

Apply a small amount of solder on one pad.

Solder on one pad

Then use tweezers to place the diode on the pads and reheat the solder to secure the diode.

Solder diode

Now you can solder the second pad.

***

## SWITCH SOCKETS

Here you can apply the same technique as used for the diodes: Apply some solder on one of the pads first.

switch sockets pad

Then place the switch socket in the silk screen markings and reheat the solder. Apply some pressure with a pair of tweezers to make sure the socket is fully seated.\
Now solder the second pad.

switch socket soldered

***

## RESET SWITCHES

The reset switches are a bit fiddly to solder. It helps to apply a really thin film of solder to the outer pads first. Then hold the switch in place with tweezers and solder the big pads on the left and right of the switch (they do not fulfill any electrical purpose, but serve to hold the switches in place). If the switch is seated correctly flip the PCB and solder the pads in the middle from below.

reset switch

***

## TRRS JACKS

Install the TRRS jack on the top side of the PCB. The place where you should insert it is marked with a white line.
You may want to use some masking tape to hold it in place since you need to solder it on the bottom.

TRRS jack soldered

***

## HAPTIC FEEDBACK (optional)

> **Note**
> Currently, haptic feedback only works on the primary side of your keyboard, which is a limitation of QMK.

Apply some solder to the jumpers on the top to bridge them.

haptic feedback Jumper

Insert the module from below with the motor facing upwards. Then insert the pin headers from below.

haptic feedback pins

Now you can solder the pins and use a flush cutter to snap off the excess. Remember to hold your hand above them or wear eye protection while doing so.

haptic feedback snap of pins

You can also use a screw and a nut to stabilize the module further. But this step is optional.

haptic feedback solder

***

## SPEAKER (optional)

> **Note**
> Currently the speaker only works on the primary side of your keyboard, which is a limitation of QMK. Currently, you need to use [this PR](https://github.com/qmk/qmk_firmware/pull/17723) to make the audio feature work with the RP2040.

Soldering the speaker is pretty simple. Apply a tiny bit of solder on one of the pads, use tweezers to hold the speaker in place and reheat the solder. After that apply solder to the other pad.

speaker

***

## TRACKBALL (optional)
> **Note**
> While the hardware side should already work fine, I still need to add the code for the trackball.

TBA

***

## ENCODERS

Mount the rotary encoder on the top side of the PCB. It should click into place maybe requiring a firm press. If it's seated correctly solder the pins on the bottom.

encoder

***

## OLEDs

> **Warning**
> Make sure the keyboard is fully functional before soldering the OLEDs, since they're the only components that cover pins, you won't be able to access them once they are in place.

First step should be to bridge the jumpers on the top of the PCB next to the OLED.

OLED bridge jumpers

> **Note**
> The OLED needs to be as flush to the PCB as possible to fit under the switchplate.

You need to remove the plastic part, which is usually attached to the OLED, from the headers, while keeping the pins. For me, the easiest way is to use flush cutters to snap the plastic in half, which allows you to remove the parts easily. You probably need to bend the pins back in place after doing this.

OLED pin split

You also need to cover the back of the OLED with electrical tape, to prevent shorts with the microcontroller pins. Especially the top part with the copper traces is important.

OLED tape on bottom

Insert the OLED on the top of the PCB. Make sure it sits as flush with the PCB as possible. Maybe hold it in place with some masking tape.

> **Note**
> You could also temporarily install the switchplate over the OLED, using a few switches. This way you make sure it's exactly in the right spot and rotation.

Solder the OLED into place.

OLED soldering

Now use flush cutters to trim the top and bottom pins. Especially the top pins should be as short as possible to avoid interference with the switch plate.

OLED flush cutter

If you use a metal switch plate consider covering them with electrical tape to prevent shorts.

OLED tape on top

> **Note**
> If you need to desolder the OLED or fix its placement just apply a lot of solder to the four pins to connect them. This way you can heat all four pins at once and remove it by gently applying force to the bottom edge of the OLED module. Be really careful not to use too much pressure, since you could rip off a pad or destroy the OLED (which happens pretty fast).

OLED desolder

***

## CLEANING

This is what your finished PCB probably will look like. You can use an old toothbrush and some isopropanol to clean it from residues. 

Finished PCB

***

## FIRMWARE

### AVR-based ProMicro 
**e.g. Pro Micro / Elite-C / Puchi-C**

If you have not already flashed the firmware to the microcontroller you should do it now, to make sure everything works, before inserting it into the case.\
[Here](https://github.com/GEIGEIGEIST/qmk-config-klor) you can find the QMK firmware for the KLOR.\
Copy the **klor** folder into the **keyboards** directory of your qmk installation.\
Then use [QMK MSYS](https://msys.qmk.fm/) (or the command line tool of your choice) to compile it with this command:

``qmk compile -kb klor -km default`` 

This will create a file called **klor_default.hex** in your **qmk_firmware** folder.\
Open [QMK Toolbox](https://github.com/qmk/qmk_toolbox) and locate the **klor_default.hex** file.\
Connect the ProMicro/keyboard and press the reset button (or connect the RST and GND pins on the ProMicro). QMK toolbox should show a connected device.\
Press **flash** in QMK toolbox to flash the firmware on your microcontroller.

QMK toolbox

### RP2040 ProMicro 
**e.g. Adafruit KB2040 / Sparkfun Pro Micro RP2040 / Boardsource Blok / Elite-Pi / Sea-Picro**

Copy the **klor** folder into the **keyboards** directory of your qmk installation.\
Then use [QMK MSYS](https://msys.qmk.fm/) (or the command line tool of your choice) to compile it with this command:

``qmk compile -kb klor/rp2040 -km default``

This will create a file called **klor_rp2040_default.uf2** in your **qmk_firmware** folder.\
The first time you need to keep boot pressed, then press reset and release boot. This will open the flash memory of your MicroController as a device in your OS.\
Copy the **klor_rp2040_default.uf2** there to flash it. 

> **Note**
> After flashing the firmware the first time you can access the flash memory by double pressing the reset button on your keyboard or define a software reset key by using **QK_boot** as keycode.

***

## 3DP CASE

Here you can find the STL files for the case. I got them printed in PA12-HP Nylon (Multi Jet Fusion printing) by [JLCPCB](https://jlcpcb.com/3d-printing), which seemed pretty reasonably priced, for the level of detail.

3DP case

Insert the PCB first. Starting with inserting the microcontroller in the cutout at the top.

3DP case insert MCU

Then lower it into the case. To make it fit, you probably need to bend a bit the part of the case containing the holes for reset switch and TRRS jack.

3DP case bend

The TRRS jack should snap in the provided hole.

3DP case trrs

Insert the standoffs in the PCB and screw them into the bottom of the case using the countersunk screws.

3DP case standoffs

Now you can insert the plate and screw it to the case using the center standoff. 

3DP case plate

***

## ACRYLIC PARTS

Here you can find the files for the acrylic parts. Made from smokey acrylic (by a laser cutting service) it will hide the OLED, while still allowing it  to shine through the top layer. It will look best if you can get a pretty dark type, like 7C83 by PlexiGlas (used by formulor.de for example).\
If you want to get rid of the shine you can carefully sand the parts with some really fine sanding paper (I used a 2000 sanding pad).\
You need to glue the ring to the top right part using acrylic glue (Acrifix for example). Be careful to apply only a really thin layer using a toothpick.\
If you choose a case with the KLOR logotype you can emphasize it by retracing it with some sort of white paint marker. Use turpentine or something similar to get rid of the excess paint.

Screw the acrylic parts on top of the plate.

acrylic parts on top of plate

***

## KNOBS

The design works best with 23mm (0.9") diameter encoder knobs. My recommendation would be a knob from kilo international with a number beginning with 90 (which means a 0.9" diameter) like the OEDNI-90-4-7 shown here.

OEDNI-90-4-7

***

## FINAL BUILD

This is how the final keyboard will look like. In this picture, I use RAMA Grid keycaps in NOCT.

final KLOR build

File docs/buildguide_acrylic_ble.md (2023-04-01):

# KLOR BUILD GUIDE (STACKED ACRYLIC CASE BLE) [WIP]

## PART LIST

### REQUIRED PARTS

| Part name | Count | Remarks | 
| :--- | :---: | :--- |
| KLOR PCB | 02 | You can find the files for it [here](/PCB/) |
| Nice!Nano | 02 | Alternatively, you can use another controller with similar pinout and bluetooth capabilities like the Puchi-BLE |
| MX Key switch | 42 | 40 switches for Konrad / 38 switches for Yubitsume / 36 switches for Saegewerk |
| switch socket | 42 | 40 sockets for Konrad / 38 sockets for Yubitsume / 36 sockets for Saegewerk |
| diodes 1N4148W| 44 | These are surface mount diodes in SOD123 package. 42 for Konrad / 40 for Yubitsume / 38 for Saegewerk |
| 1u MX keycaps | 42 | 40 keycaps for Konrad / 38 keycaps for Yubitsume / 36 keycaps for Saegewerk |
| OLED module | 02 | SSD1306 128x64 pixel OLED Displays |
| reset button  | 02 | Alps SKRTLAE010 |
| power switch  | 02 | MSK12C02 |
| EC11 encoder  | 02 | You can use any EC11 encoder, but it will look better if you use a short one, like the EC11N1524402 |
| encoder knob  | 02 | The design works best with a 2,2cm encoder knob. I'd recommend kilo international knobs with a number starting with 90. You could also use the [knob](/knob/) I designed for the KLOR, based on the kilo knob. 
| Lipo battery  | 02 | 
| USB cable | 01 | For connecting the keyboard with your PC |

### OPTIONAL PARTS

| Part name | Count | Remarks | 
| :--- | :---: | :--- |
| MCU sockets | 04 | For socketing your MCU. Highly recommended |
| MCU pins | 48 | In combinatin with the MCU sockets |
| JST Jack | 02 | JST PH |
| SK6812 Mini LED (not Mini-E) 3535 size | 42 | 40 LEDs for Konrad / 38 LEDs for Yubitsume / 36 LEDs for Saegewerk |
| TRRS jack | 02 | MJ-4PP-9 or PJ320A You can add TRRS jacks, so you can swap out the Microcontroller to make it a wired board |
| TRRS cable | 01 | See TRRS jack |
| [trackball](https://bit-trade-one.co.jp/selfmadekb/adtb7m/) | 01 | Pixart PAW3204OA. Available at [Yushakobo](https://shop.yushakobo.jp/products/adtb7m) |
| [level converter](https://github.com/sekigon-gonnoc/LevelConverterForTrackballModule) | 01 | Needed to use the trackball. You can get it from [Yushakobo](https://shop.yushakobo.jp/products/a0800tl-01-1/) |
| [tenting puck](https://splitkb.com/products/tenting-puck)| 02 | SplitKB Tenting Puck |

### ACRYLIC CASE PARTS

| Part name | Count | Remarks | 
| :--- | :---: | :--- |
| acrylic parts | 02 | Find the case files [here](/case/acrylic/) |
| switch plate | 02 | 1.5mm switch plate |
| 9mm M2 standoffs | 22 | Up to 22 9mm round standoffs for the actual case (check the appropiate puzzleguide) |
| 7mm M2 standoffs | 12 | 7mm round standoffs for holding the PCB in place |
| 6mm M2 screws | 56 | Up to 56 regular 6mm M2 screws (check the appropiate puzzleguide) |
| 5mm M2 wafer head screws | 12 | These screws need a flat head to fit under the acrylic top layer |

## INTRODUCTION

Here is an overview of where and on which side each component needs to be soldered (click on the image to see a larger version).

KLOR solder guide

To see what component needs to sit where you can take a look at the [interactive HTML BOM](https://htmlpreview.github.io/?https://github.com/GEIGEIGEIST/KLOR/blob/main/docs/klor_rev1-3_ibom.html).

> **Warning**
> This interactive HTML BOM does show where each component is located, but please still refer to the solder guide above to see if a component needs to go on the top or bottom of the PCB.

Be aware that for the 3D printed case some components need to be soldered on the opposite side.\
Some people mark the top and bottom with tape to keep track of which side is which, as the PCB is reversible.\
Beginn with the flat components and progress to the higher ones, ending with the OLEDs and the encoders.

***

## BREAK OFF PARTS (optional)

If you choose a layout [other than](/README.md#layouts) Polydactyl you should remove the unnecessary parts. Use a flush cutter to snip through the support sections. You can also use a boxcutter to carve in grooves, which makes it easier to break on the right spot. 

> **Warning**
> Be very careful with this step, since there is a risk to break the PCB. Probably it would be best to beginn with this step, to avoid loosing already soldered parts.

break off parts

You can use a file to smooth out the edges, but you should wear a mask while doing this, since the FR4 dust is considered to be toxic.

***

## MICROCONTROLLER

> **Warning**
> First flash the microcontroller to make sure it works, before soldering it in.

Unlike most other boards here the microcontroller needs to be mounted on the bottom, with the components facing upwards (to the PCB).\
Feel free to use the included header pins, but it's highly recommended to use MillMax low profile sockets.\
Place the sockets in the marked spots on the bottom side of the PCB.

MCU sockets

You can keep them in place by using masking tape.

sockets taped

Then you can flip the board to solder in the sockets from the top.
Flip it again and insert the pins into the sockets.

> **Note**
> Use tweezers to insert them. Don't apply too much force, you will feel them snap in. After that, you can carefully apply some pressure, using a flat object to make sure they're fully seated. 

MCU pins

Now place your microcontroller on the pins (components facing the PCB) and solder it to them.\
You can use flush cutters to trim the header pins.

MCU solder

> **Warning**
> When trimming with flush cutters wear eye protection or hold your hand close above the pins. Otherwise sharp metal pins flying around might hurt you.

***

## LEDS (optional)

> **Note**
> If you use a layout with three thumbs, instead of four, you need to bridge the 'lost thumb?' jumper below the TRRS sockets on the primary and secondary PCB, since the led chain lost its beginning. 

Lost thumb jumper

LEDs are very heat sensitive. So it's a good idea to solder the pads on the PCB bottom first and then insert the LED.

LED solder pads

While the bottom of the PCB is facing you, insert the LEDs in the holes. The lens should face the table.

LED in place

This image depicts the correct orientation.\
The L shaped pad on the LED need to be connected to the square marked pad.

LED orientation1

> **Note**
> While the orientation is uniform within a half, it differs between left and right.

> **Warning**
> It's recommended to solder the LEDs in at 220º, since they're pretty heat sensitive. Personally, I had a hard time keeping it below 270º. So my advice would be while soldering the first pad on every LED, try to be really quick. Then solder the second pad on every LED, starting with the first LED. This way they can cool down in the meantime.

Make sure the solder always builds a strong connection between the pad on the LED and the pad on the PCB. 

LED connection

The advantage of soldering in the microcontroller first is that you can occasionally check if all the LEDs work before continuing. 

KLOR LED working

This graphic shows the order in which the LEDs are chained together.

KLOR LED order

> **Note**
> While it's possible to use LEDs in a BLE board be aware that this will hugely decrease your battery life. 

***

## DIODES

The diodes needs to be soldered on the bottomm of the PCB. Pay attention to their orientation:  They have a small line on one side, which should be on the side the arrow on the PCB is facing to.

<p align="center">
<picture>
  <source media="(prefers-color-scheme: dark)" srcset="/docs/images/buildguide/diodes_dark.svg">
  <source media="(prefers-color-scheme: light)" srcset="/docs/images/buildguide/diodes_bright.svg">
  diode orientation
</picture>
</p>

Apply a small amount of solder on one pad.

Solder on one pad

Then use tweezers to place the diode on the pads and reheat the solder to secure the diode.

Solder diode

Now you can solder the second pad.

***

## SWITCH SOCKETS

Here you can apply the same technique as used for the diodes: Apply some solder on one of the pads first.

switch sockets pad

Then place the switch socket in the silk screen markings and reheat the solder. Apply some pressure with a pair of tweezers to make sure the socket is fully seated.\
Now solder the second pad.

switch socket soldered

***

## POWER SWITCHES

Apply a tiny bit of solder on one of the bigger, outer pads on top of the PCB. The power switch has some tiny knobs on its bottom, which fits into the PCB holes. Hold it in place with tweezers and than reheat the solder on the pad. After this you can solder the other pad and the three pins.

power switch

***

## JST JACKS (optional)

Insert the legs of the JST jack into the bottom of the PCB with the open side facing inwards

JST jack

Now use some masking tape to keep it in place, since you need to solder it from the top.

JST tape

You also need to bridge the jumpers next to the connector to make it work.

JST brigded jumpers

> **Note**
> While it's easier to swap out batteries if they already got a JST-PH connector you can also solder the battery to the **+ RED** and **- BLACK** pinholes. This way you don't need to bridge the jumpers.

battery connector

***

## RESET SWITCHES

The reset switches are a bit fiddly to solder. It helps to apply a really thin film of solder to the outer pads first. Then hold the switch in place with tweezers and solder the big pads on the left and right of the switch (they do not fulfill any electrical purpose, but serve to hold the switches in place). If the switch is seated corretly flip the PCB and solder the pads in the middle from below.

reset switch

***

## TRRS JACKS (optional)

> **Warning**
> You don't need the TRRS jacks for running the KLOR with ZMK. Actually you can damage your board when connecting it through TRRS, while also connected to a battery.

Install the TRRS jack on the bottom side of the PCB. The place where you should insert it is marked with a white line.
You may want to use some masking tape to hold it in place, since you need to solder it on the bottom.

TRRS jack taped

TRRS jack soldered

***

## TRACKBALL (optional)

> **Note**
> While the hardware side should already work fine, I still need to add the code for the trackball.

TBA

***

## ENCODERS

> **Note**
> Currently ZMK only supports encoders on the primary side of split keyboards. 

Mount the rotary encoder on the top side of the PCB. It should click into place maybe requiring a firm press. If it's seated correctly solder the pins on the bottom.

encoder

***

## OLEDs

> **Warning**
> Make sure the keyboard is fully functional before soldering the OLEDs, since they're the only components which cover pins, you won't be able to access once they are in place.

First step should be to bridge the jumpers on the top of the PCB next to the OLED.

OLED bridge jumpers

> **Note**
> The OLED needs to be as flush to the PCB as possible to fit under the switchplate.

You need to remove the plastic part, which is usually attached to the OLED, from the headers, while keeping the pins. For me the easiest way is to use flush cutters to snap the plastic in half, which allows you to remove the parts easily. You probably need to bend the pins back in place after doing this.

OLED pin split

You also need to cover the back of the OLED with electrical tape, to prevent shorts with the microcontroller pins. Especially the top part with the copper traces is important.

OLED tape on bottom

Insert the OLED on the top of the PCB. Make sure it sits as flush to the PCB as possible. Maybe hold it in place with some masking tape.

> **Note**
> You could also temporarily install the switchplate over the OLED, using a few switches. This way you make sure it's exactly in the right spot and rotation.

Solder the OLED into place.

OLED soldering

Now use flush cutters to trim the top and bottom pins. Especially the top pins should be as short as possible to avoid interference with the switch plate.

OLED flush cutter

If you use a metal switch plate consider to cover them with electrical tape to prevent shorts.

OLED tape on top

> **Note**
> If you need to desolder the OLED or fix its placement just apply a lot of solder to the four pins to connect them. This way you can heat all four pins at once and remove it by gently applying force to the bottom edge of the OLED module. Be really carefull not to use too much pressure, since you could rip off a pad or destroy the OLED (which happens pretty fast).

OLED desolder

***

## CLEANING

This is how your finished PCB probably will look like. You can use an old toothbrush and some isopropanol to clean it from residues. 

Finished PCB

***

## FIRMWARE

If you have not already flashed the firmware to the microcontroller you should do it now, to make sure everything works, before inserting it into the case.\
[Here](https://github.com/GEIGEIGEIST/zmk-config-klor) you can find the ZMK firmware for the KLOR.\
You need to create an own fork of it. In this fork you can edit the keymap to trigger an Github action, which will create your firmware. 

***

## STACKED ACRYLIC CASE

> **Note**
> Since there are a lot of different parts please check the 'puzzle guide' which you can find in the same folder than the case files of your layout. 

Screw the standoffs onto the bottom plate. You can find the locastion of the 7mm standoffs and 9mm standoffs in the 'puzzle guide', but as a rule of thumb the 9mm standoffs should be on the outside, holding the case parts, while the 7mm standoffs will hold the PCB and switchplate.\
(The dark shapes on the bottom are pieces of deskmat, I use as bumpers.) 

acrylic bottom

Next you should align the parts of the first layer to the outer standoffs. The parts for the left and right case are interchangeable.

acrylic first layer

Now you can insert the PCB and add the other layers.

acrylic all layers

 Align the plate and screw them to the center standoffs.

 acrylic switchplate

For this step you need the 5mm wafer head screws, since other screwheads would intersect with the top layer.

wafer head screws

Finally attach the top plate and insert the switches into the plate.

acrylic top plate

***

## KNOBS

The design works best with 23mm (0.9") diameter encoder knobs. My recomendation would be a knob from kilo internationl with a number beginning with 90 (which means a 0.9" diameter) like the OEDNI-90-4-7 shown here.

OEDNI-90-4-7

***

## FINAL BUILD

This is how the final keyboard will look like. In this picture you see the KLOR saegewerk, with RAMA Grid keycaps in NOCT.

KLOR acrylic case

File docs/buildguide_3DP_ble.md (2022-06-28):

# KLOR BUILD GUIDE (3DP CASE BLE) [WIP]

Since the BLE versin of the 3D print case is untested this build guide isn't created yet.

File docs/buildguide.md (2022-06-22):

# KLOR BUILD GUIDE [WIP]

## PART LIST

### REQUIRED PARTS

| Part name | Quantity | Remarks | 
| --- | --- | --- |
| KLOR PCB | 02 | |
| ProMicro | 02 | Alternatively you can use another controller, with a similar pinout like the Elite-C, Puchi-C, KB2040 dda. |
| MX Key switch | 42 | 40 switches for Konrad / 38 switches for Yubitsume / 36 switches for Saegewerk |
| Switch socket | 42 | 40 sockets for Konrad / 38 sockets for Yubitsume / 36 sockets for Saegewerk |
| Diodes 1N4148W| 44 | They are surface mount diodes in SOD123 package. 42 for Konrad / 40 for Yubitsum / 38 for Saegewerk |
| 1u MX Keycaps | 42 | 40 keycaps for Konrad / 38 keycaps for Yubitsume / 36 keycaps for Saegewerk |
| OLED module | 02 | SSD1306 128x64 pixel OLED Displays |
| Reset Button  | 02 | Alps SKRTLAE010 |
| TRRS jack | 02 | |
| TRRS cable | 01 | Alternatively you can use a TRS cable for [half-duplex](https://github.com/qmk/qmk_firmware/blob/master/docs/serial_driver.md#usart-half-duplex)|
| EC11 encoder  | 02 | You can use any EC11 encoder, but it will look better if you use a short one, like the EC11N1524402 |
| encoder knob  | 02 | The design works best with a 2,2cm encoder knob. I recommend kilo international knobs with a number starting with 90. 
| USB cable | 01 | For connecting the keyboard with your PC |

### OPTIONAL PARTS

| Part name | Quantity | Remarks | 
| --- | --- | --- |
| MCU sockets | 04 | For socketing your MCU. Highly recommended |
| MCU pins | 48 | In combinatin with the MCU sockets |
| [Haptic Feedback Module](https://shop.pimoroni.com/products/drv2605l-linear-actuator-haptic-breakout) | 01 | Pimoroni Haptic Buzz |
| speaker | 01 | Mallory AST1109MLTRQ or Keliking KLJ-1102 |
| [trackball](https://bit-trade-one.co.jp/selfmadekb/adtb7m/) | 01 | Pixart PAW3204OA. You can get it from [Yushakobo](https://shop.yushakobo.jp/products/adtb7m) |
| [level converter](https://github.com/sekigon-gonnoc/LevelConverterForTrackballModule) | 01 | Needed to use the trackball. You can get it from [Yushakobo](https://shop.yushakobo.jp/products/a0800tl-01-1/) |
| [tenting puck](https://splitkb.com/products/tenting-puck)| 02 | SplitKB Tenting Puck |

### 3DP CASE PARTS

| Part name | Quantity | Remarks | 
| --- | --- | --- |
| 3D printed case | 02 | |
| acrylic parts | 02 | Three parts and one ring per side |
| switch plate | 02 | 1.5mm switch plate |
| 7mm M2 standoffs | 16 | |
| 6mm M2 screws | 16 | |
| 6mm M2 countersunk screws | 16 | The bottom only supports countersunk screws |

### ACRYLIC CASE PARTS

| Part name | Quantity | Remarks | 
| --- | --- | --- |
| acrylic parts | 02 | |
| switch plate | 02 | 1.5mm switch plate |
| 9mm M2 standoffs | 22 | Up to 22 9mm standoffs for the actual case (check the appropiate puzzleguide) |
| 7mm M2 standoffs | 12 | 7mm standoffs for holding the PCB in place |
| 6mm M2 screws | 56 | Up to 56 regular 6mm M2 screws (check the appropiate puzzleguide) |

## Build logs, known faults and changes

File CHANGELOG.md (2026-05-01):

# CHANGELOG
10/09/2024
-  Here we go! The new 1.5 Revision in its first iteration has been built and works as expected solving little issues remaining and improving greatly over the previous versions.
-  The combination of direct USB 5V supply and distribution between the two boards, full duplex transmission, handedness hardware detection, dedicated lock status LED and integrated haptic transducer and driver all make this version a killer ergo keyboard! It is really super bright now and the main MCU does not overheat anymore.

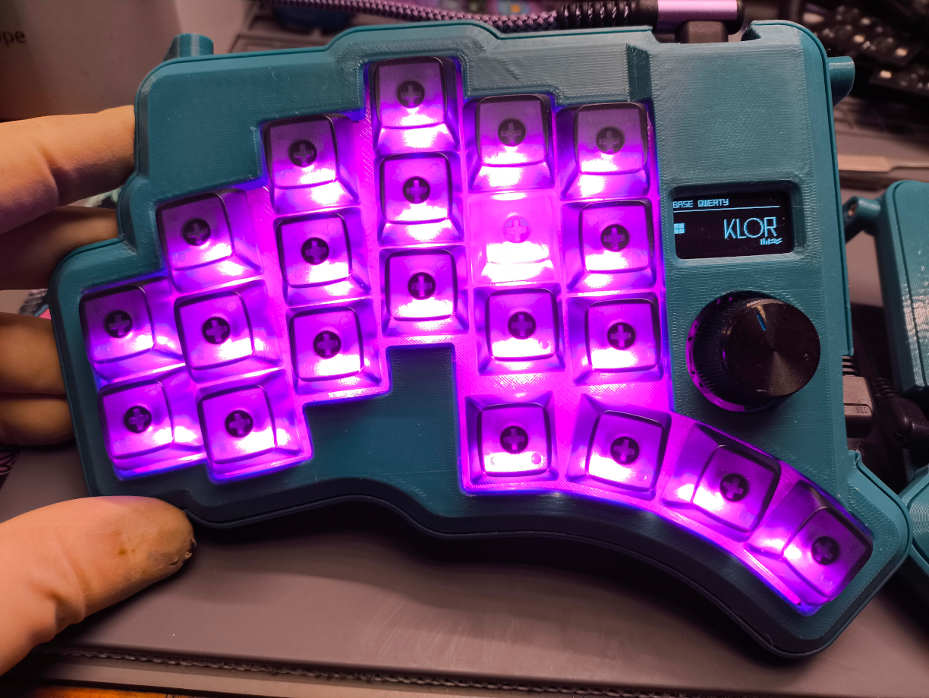
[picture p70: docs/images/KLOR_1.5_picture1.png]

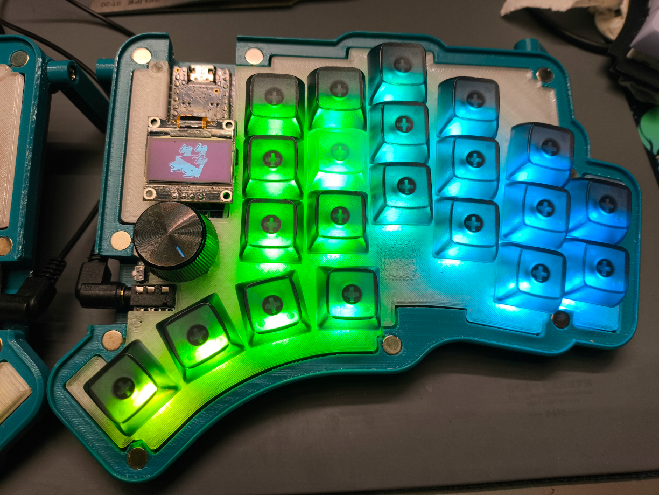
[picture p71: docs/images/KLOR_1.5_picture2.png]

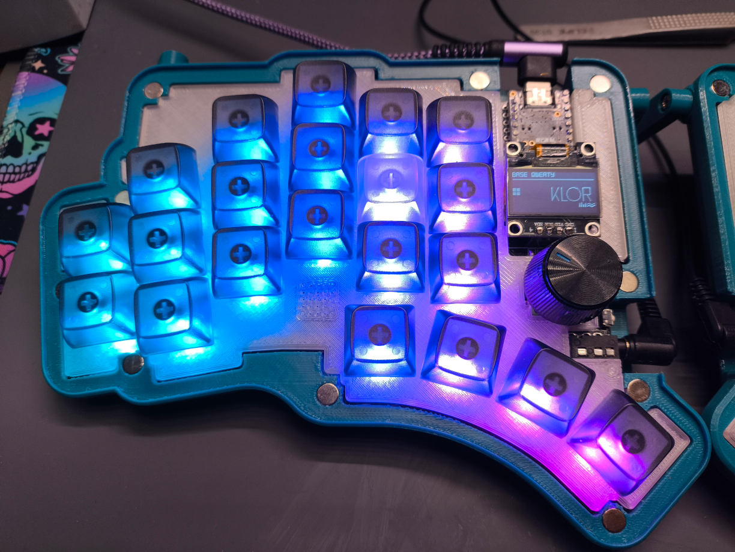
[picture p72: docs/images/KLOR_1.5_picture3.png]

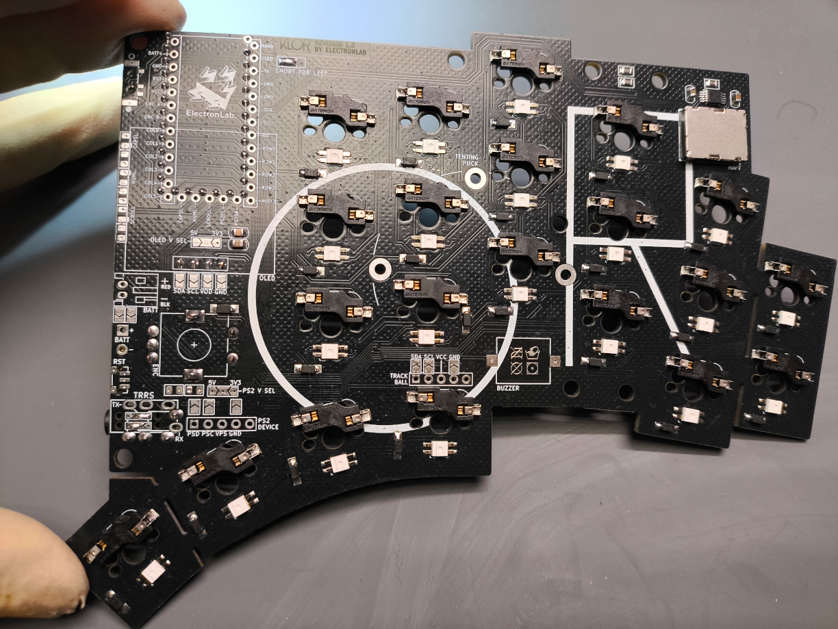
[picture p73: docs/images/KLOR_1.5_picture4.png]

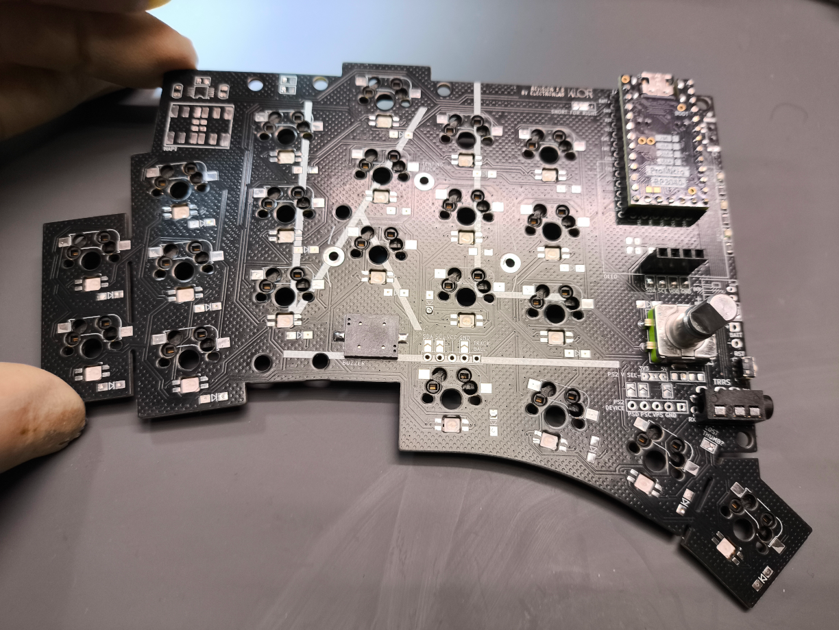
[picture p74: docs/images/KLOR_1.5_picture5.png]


07/09/2024
-  For those interested in the KLOR project I have finished developping a new version of KLOR PCB with an important revision 1.5 bringing the following upgrades:



   -  Significant improvement of the power distribution topology : direct USB 5V powering of the LED strips with inline capacitance, distribution of the 5V supply between both sides to share the load between both MCU regulators with RX/TX voltage clamping protection. Original design relied on the master side MCU linear voltage regulator to power both keyboard halves + LED strings + onboard I2C devices. This resulted in very high load on a single linear regulator added to the fact that ARGB LED strings and OLED displays are designed to run on direct 5V out of the box and will operate nominaly at this voltage (higher brightness and less heat generated by the regulators).
   -  On board soldered haptic module allowing more switch options and better transmission of vibrations
   -  Ability to chose the OLED primary voltage to 5V or 3.3V
   -  Dedicated LED for NUM, CAPS and SCROLL lock status for implementations without OLED displays
   -  Support of PS2 and I2C pointing devices with ability to select protocol and primary voltage to 5V or 3.3V
   -  RP2040 Promicro full pinout support
   -  Ability to set the handedness at hardware level
   -  Ability to set the TRRS wiring with symmetrical or inverted pinout for full duplex serial communications  
   -  South facing SK6812 Mini-E for all versions
   -  Exists in full height switch, low profile Gateron KS33 and low profile Kailh V2
   -  Still compatible with all ProMicro boards, optimized for QMK on RP2040

-  I should get the first PCBs tomorrow for first builds, stay tuned!!

01/09/2024
-  While working on a revision of the PCB, I noticed another issue in the original design. If using the TRRS connection on a wired build, the master MCU board is actually powering the totality of the keyboard with its 3.3V voltage regulator as the TRRS transports the down converted 3.3V to the secondary MCU VCC, thus bypassing its regulator. This means that the two MCU, the two LED strips and the I2C devices get their 3.3V from the regulator of the master MCU board only, which tends to overheat quite a bit and is most likely not designed for such a heavy load. Another issue with this topology is that the ARGB LED typically require 5V VCC to operate nominaly, while in this case they are powered with 3.3V only. It works but it is completly unnecessary to down convert the USB/Battery voltage to 3.3V for the LED strips. Note that this has nothing to do with the contol logic level which MUST be at 3.3V. I will be addressing those issues on a 1.5 revision coming soon...

31/08/2024
-  Added support for VIAL firmware for RP2040 boards. You can now compile :
   
      the "default" layout using [QMK toolchain](https://github.com/qmk/qmk_firmware) and the command :

            qmk compile -kb klor -km default -c
   
      or "vial" layout using [vial-qmk toolchain](https://github.com/vial-kb/vial-qmk) and the command :

            make clean && make klor:vial
   
-   NB : In both cases I had to modify the file ./platforms/chibios/boards/QMK_PM2040/configs/mcuconf.h and change the line :

           #define RP_PWM_USE_PWM4                     FALSE
           to
           #define RP_PWM_USE_PWM4                     TRUE
    
-   Also be aware that I have now enabled firmware based handedness definition ([#define EE_HANDS setting](https://docs.qmk.fm/features/split_keyboard)) so you should flash the firmware using the following commands for left and right keyboard sides :
-   
   For QMK environment
    
             qmk flash -kb klor -km default -c -bl uf2-split-left
             qmk flash -kb klor -km default -c -bl uf2-split-right
    
  For VIAL-QMK environment
     
             qmk flash -kb klor -km vial -c -bl uf2-split-left
             qmk flash -kb klor -km vial -c -bl uf2-split-right

-  Make sure you switch your serial communication to HALF DUPLEX as software pin swap used for full duplex does not seem to work well with firmware based handedness detection. If you alyays want to plug one side of the keyboard then you can set the master side in config.h and switch to full duplex with software pin swap. This will require a little testing but it will work eventually

28/08/2024
-  While playing with QMK I have noticed that the original 1.3 design carried a wiring flaw on the minijack footprint and PCB traces. The RX/TX are symetrical between the two sides which makes it impossible to define the transmission protocol in QMK as serial full duplex with RP2040 ProMicro boards if you don't specify a pin swap command. By default the stock firmware uses bitbang driver on a single pin which is not optimal and made the use of a TRRS link unnecessary as 3 pins cable would suffice. If you use these boards you should set the following in the config.h for QMK if using RP2040 ProMicro boards.
      
                  //Full Duplex communication
                  #define SERIAL_USART_TX_PIN GP4     // USART TX pin
                  #define SERIAL_USART_RX_PIN GP1     // USART RX pin
                  #define SERIAL_USART_FULL_DUPLEX
                  #define SERIAL_USART_PIN_SWAP

-  In case your MCU can only use a single pin for communications, it is recommended to use half duplex serial instead of bitbang.
      
                  //Half Duplex communication
                  //#define SERIAL_USART_TX_PIN GP1     // USART TX pin
       
-  More about this matter [here](https://docs.qmk.fm/drivers/serial)

27/08/2024
-  Validation of the alternative haptic module. You may now add it to your existing board. It is working great
-  Did some minimal tracks cleanup on all versions with Kicad cleanup tools. It was mainly some unmerged tracks.
-  Moved all files to Kicad 8 version. Please upgrade your version if required.
-  At the request of some users of the community I have made an initial "special" low profile version for KS33/V2 Gateron switches with south facing LED. Beware that this version is untested yet in terms of production validation. It will most likely be fabricated by JLCPB as it clears DRC, but I haven't assembled one yet. Also keep in mind the following points :

    - There will be some interferences with the haptic module as there is no way I can move it up sufficiently on the existing PCB cutout. I would have to redesign the top corner which would impact enclosure compatibility. Haptic module can be mounted but it will have to be a little bit spaced from the back of the PCB to clear the switch socket.
    - I have moved the puck mounting holes up a little bit. It now sits in between the 1.3 and 1.4 positions
    - Because the KS33 hotswaps have a very diferent pinout compared with standard Cherry, they don't play as well with the recto-verso design of the KLOR. In particular you may find to lack a little bit of soldering surface on the right pad. It should be just enough to solder the pad. This is due to the pad interfering with the other side hole. Nothing I can do here apart from duplicating the design for right and left sides.
    - Obviously you will need some Gateron low profile V2 hotswap sockets for this version (compatible with Gateron KS33/V2 low profile type switches). These are easilly obtainable on Aliexpress I use them for another project.Only Gateron low profile V2 sockets can be used. No other brands will work on this design.

23/08/2024
-  Upddated FIRMWARE directory with working config files for QMK for RP2040 and ZMK for NiceNanoV2. These are not perfect but both firmware compile without errors and have the maximum functionalities enabled by default.
-  Added precompiled [qmk](https://github.com/Lefuneste83/KLOR/tree/main/FIRMWARE/Ready-to-flash/qmk-RP2040) and [zmk](https://github.com/Lefuneste83/KLOR/tree/main/FIRMWARE/Ready-to-flash/zmk-NiceNanoV2) firmware
-  For extra convienence if you intend to modify your firmware for a smaller layout, I have created a link to :

    -  A [full POLYDACTYL layout](http://www.keyboard-layout-editor.com/#/gists/8ff2b448f2ef6c56c2b932e83ebf040f)
    -  A [KONRAD layout](http://www.keyboard-layout-editor.com/#/gists/49ff09e68b46feb39760467424a4601a)
    -  A [YUBITSUME layout](http://www.keyboard-layout-editor.com/#/gists/dc3fdb427b3102ccbf85252e2e278918)
    -  A [SAEGEWERK layout](http://www.keyboard-layout-editor.com/#/gists/b3775d73a84de0d544ea3bf84bafb047)

09/08/2024
- Correction of a 0.45 mm interference between hot swap socket and bottom of haptic buzz module. The module has been moved upwards by 0.6 mm to clear the interference for those willing to install the stock haptic module.
- An alternative design for a DIY haptic module is included if you can get a DRV2605LDGSR driver chip and a ELV1411A linear motor. Hot air/plate soldering is required. This module is 0.8 mm shorter so there will definitely be no interference whatever version of PCB you have. Attachment hole placment is unchanged relative to motor and pins locations in order to preserve mechanical compatibility. I recommend a thinner PCB (1.2 mm) for this module.

07/08/2024
-  Production validation of the new design. Full build completed and tested. Current Paste Layers are functionnal for those willing to order stencils.

25/07/2024
-  Initial commit with refactored PCB design for SK6812 Mini-E South facing ARGB LEDs

30/07/2024
-  Correction to SMD footprints for Paste Layers for diodes, reset switch and speaker.
-  ZMK Firmware modifications in order to be able to set per rotation pulses for each encoder. Both encoders work as expected. RGB light has been enabled by default as well.

--> If you intend to generate your own gerbers instead of the ones provided, make sure to process drill files AND flag the "Substract soldermask layer from copper pads" option (otherwise the KLOR Logo will superimpose on some of the SMD pads rendering soldering impossible without manual scratching of the covered pads). Guess how I know...

01/05/2025

- add rev1_5 which attempts to swap out one of the switches on the thumb cluster (SW22) with a 5 way switch with a desing based on the one used in [the Djinn](https://github.com/tzarc/keyboards/tree/main/Djinn)

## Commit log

2022-06-21 add PCB files
    [klor1_3-B_Mask.gbs, klor1_3-B_Paste.gbp, klor1_3-B_Silkscreen.gbo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]
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2022-06-27 dies und das
    [KLOR_konrad_3DP_switchplate.dxf, KLOR_konrad_acrylic_switchplate.dxf, KLOR_polydactyl_3DP_switchplate.dxf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]
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2022-06-28 update switchplates
    [KLOR_konrad_acrylic_case_switchplate.dxf, KLOR_polydactyl_acrylic_case_switchplate.dxf, KLOR_saegewerk_acrylic_case_switchplate.dxf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]
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2022-07-01 add case 3DP case files
    [KLOR_konrad_case_L.stl, KLOR_konrad_case_R.stl, KLOR_konrad_case_ble_L.stl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]
2022-07-01 update case 3DP case files
    [KLOR_konrad_case_L.stl, KLOR_konrad_case_ble_L.stl, KLOR_polydactyl_case_L.stl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]
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2022-07-07 update 3DP case files
    [KLOR_konrad_case_L.stl, KLOR_konrad_case_R.stl, KLOR_konrad_case_ble_L.stl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]
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2022-07-08 update PCB files and gerbers
    [klor1_3-B_Mask.gbs, klor1_3-B_Paste.gbp, klor1_3-B_Silkscreen.gbo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]
2022-07-20 update acrylic case files for 3DP cases
    [KLOR_konrad_3DPcase_acrylic.dxf, KLOR_konrad_3DPcase_acrylic_logotype.dxf, KLOR_polydactyl_3DPcase_acrylic.dxf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]
2022-08-22 Update 3DP case acrylic files
    [KLOR_konrad_3DPcase_acrylic.dxf, KLOR_konrad_3DPcase_acrylic_logotype.dxf, KLOR_polydactyl_3DPcase_acrylic.dxf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]
2022-08-22 fixed case files
    [KLOR_konrad_case_L.stl, KLOR_konrad_case_R.stl, KLOR_konrad_case_ble_L.stl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]
2022-09-01 Case size fix
    [KLOR_konrad_case_L.stl, KLOR_konrad_case_R.stl, KLOR_konrad_case_ble_L.stl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]
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2024-07-09 modifié : PCB/klor1_3/KLOR.pretty/MJ-4PP-9.kicad_mod modifié : PCB/klor1_3/fp-info-cache modifié : PCB/klor1_3/gerbers/klor1_3-B_Cu.gbl modifié : PCB/klor1_3/gerbers/klor1_3-B_Mask.gbs modifié : PCB/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
    [klor1_3-B_Mask.gbs, klor1_3-B_Paste.gbp, klor1_3-B_Silkscreen.gbo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]
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2024-07-25 modifié : PCB/klor1_3/KLOR.pretty/SK6812MINI_and_cherry.kicad_mod nouveau fichier : PCB/klor1_3/klor1_3-backups/klor1_3-2024-07-23_162032.zip modifié : PCB/klor1_3/klor1_3.kicad_pro nouveau fichier :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
    [Base-Konrad.stl, BaseWithTenting-Konrad.stl, EncoderInsert-16mm.stl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]
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2024-07-25 nouveau fichier : PCB/klor1_4/_autosave-klor1_4.kicad_pcb modifié : PCB/klor1_4/gerbers/gerbers.zip modifié : PCB/klor1_4/gerbers/klor1_4-B_Cu.gbl modifié : PCB/klor1_4/gerbers/klor1_4-B_Mask.gbs mod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
    [klor1_4-B_Cu.gbl, klor1_4-B_Mask.gbs, klor1_4-B_Paste.gbp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]
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2024-07-26 modifié : gerbers.zip modifié : klor1_4-B_Cu.gbl modifié : klor1_4-B_Mask.gbs modifié : klor1_4-B_Paste.gbp modifié : klor1_4-B_Silkscreen.gbo modifié : klor1_4-Edge_Cuts.gm1 modifié : klor1_4-F_Cu.g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
    [klor1_4-B_Cu.gbl, klor1_4-B_Mask.gbs, klor1_4-B_Paste.gbp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]
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2024-07-30 modifié : PCB/klor1_4/KLOR.pretty/Buzzer_Mallory_AST1109MLTRQ_reversible.kicad_mod modifié : PCB/klor1_4/KLOR.pretty/Diode_SOD123.kicad_mod modifié : PCB/klor1_4/KLOR.pretty/SK6812MINI_and_cherry_1.k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
2024-07-30 modifié : PCB/klor1_4/gerbers/gerbers.zip modifié : PCB/klor1_4/gerbers/klor1_4-B_Cu.gbl modifié : PCB/klor1_4/gerbers/klor1_4-B_Mask.gbs modifié : PCB/klor1_4/gerbers/klor1_4-B_Paste.gbp modifié : P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
    [klor1_4-B_Cu.gbl, klor1_4-B_Mask.gbs, klor1_4-B_Paste.gbp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]
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2024-08-09 nouveau fichier : PCB/Alternate DIY Haptic Module/Gerber_Haptic-Module_Haptic-Module_2024-08-09.zip nouveau fichier : case/Alternate Case Design/535004-case-designs-for-klor-polydactyl-konrad-yubitsu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
    [Base-Konrad.stl, BaseWithTenting-Konrad.stl, EncoderInsert-16mm.stl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]
2024-08-09 Update README.md
    Inclusion of DIY haptic module. Correction of PCB for stock module
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2024-08-09 supprimé : case-designs-for-klor-polydactyl-konrad-yubitsume-and-saegewerk-model_files/535004-case-designs-for-klor-polydactyl-konrad-yubitsume-and-saegewerk-2240062f-93fd-4992-ab70-c1e3f6eb6469.pdf 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
    [Base-Konrad.stl, BaseWithTenting-Konrad.stl, EncoderInsert-16mm.stl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]
2024-08-09 modifié : ../PCB/klor1_4/fp-info-cache modifié : ../PCB/klor1_4/gerbers/gerbers.zip modifié : ../PCB/klor1_4/gerbers/klor1_4-B_Cu.gbl modifié : ../PCB/klor1_4/gerbers/klor1_4-B_Mask.gbs modifié : ../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
    [klor1_4-B_Cu.gbl, klor1_4-B_Mask.gbs, klor1_4-B_Paste.gbp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]
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2024-08-27 nouveau fichier : PCB/klor1_4_LP_KS33/KLOR.pretty/Buzzer_Mallory_AST1109MLTRQ_reversible.kicad_mod nouveau fichier : PCB/klor1_4_LP_KS33/KLOR.pretty/Diode_SOD123.kicad_mod nouveau fichier : PCB/klor1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
    [klor1_4-B_Cu.gbl, klor1_4-B_Mask.gbs, klor1_4-B_Paste.gbp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]
2024-08-27 modifié : PCB/klor1_3/gerbers/gerbers.zip modifié : PCB/klor1_3/gerbers/klor1_3-B_Cu.gbl modifié : PCB/klor1_3/gerbers/klor1_3-B_Mask.gbs modifié : PCB/klor1_3/gerbers/klor1_3-B_Paste.gbp modifié : P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
    [klor1_3-B_Mask.gbs, klor1_3-B_Paste.gbp, klor1_3-B_Silkscreen.gbo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]
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2024-08-28 supprimé : FIRMWARE/Ready-to-flash/qmk-RP2040/klor_default.uf2 modifié : FIRMWARE/qmk_rp2040/klor/config.h modifié : FIRMWARE/qmk_rp2040/klor/keyboard.json modifié : FIRMWARE/qmk_rp2040/klor/keymaps/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
    [klor1_4-B_Cu.gbl, klor1_4-B_Mask.gbs, klor1_4-B_Paste.gbp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]
2024-08-28 Update CHANGELOG.md
    Correction of the wiring error of the 1.3 original design for serial communication. Correction was made to both 1.4 versions but NOT on the 1.3 version provided on this fork.
2024-08-29 renommé : FIRMWARE/Ready-to-flash/qmk-RP2040/klor_default_mirror_serial.uf2 -> FIRMWARE/Ready-to-flash/qmk-RP2040/klor_default.uf2 supprimé : FIRMWARE/Ready-to-flash/qmk-RP2040/klor_default_crossed_s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
    [klor1_4-B_Cu.gbl, klor1_4-B_Mask.gbs, klor1_4-B_Paste.gbp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]
2024-08-29 modifié : PCB/klor1_4_LP_KS33/KLOR.pretty/MJ-4PP-9.kicad_mod supprimé : PCB/klor1_4_LP_KS33/README.md modifié : PCB/klor1_4_LP_KS33/fp-info-cache modifié : PCB/klor1_4_LP_KS33/gerbers/gerbers.zip mod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
    [klor1_4-B_Cu.gbl, klor1_4-B_Mask.gbs, klor1_4-B_Paste.gbp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]
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2024-09-03 nouveau fichier : PCB/klor1_4_LP_KS33/KLOR.pretty/KS33_Symetrical.kicad_mod modifié : PCB/klor1_4_LP_KS33/fp-info-cache modifié : PCB/klor1_4_LP_KS33/gerbers/gerbers.zip renommé : PCB/klor1_4_LP_KS33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
    [klor1_4-B_Cu.gbl, klor1_4-B_Mask.gbs, klor1_4-B_Paste.gbp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]
2026-05-01 add v1.5 schematic and pcb
    [klor1_4_LP_KS33-B_Cu.gbl, klor1_4_LP_KS33-B_Mask.gbs, klor1_4_LP_KS33-B_Paste.gbp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]
2026-05-01 remove old v1.4 ks33
    [klor1_4_LP_KS33-B_Cu.gbl, klor1_4_LP_KS33-B_Mask.gbs, klor1_4_LP_KS33-B_Paste.gbp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]
2026-05-01 move everything 1_4 -> 1_5
    [klor1_4_LP_KS33.kicad_sch]
